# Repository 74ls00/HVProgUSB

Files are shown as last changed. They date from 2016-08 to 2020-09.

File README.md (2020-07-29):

# HVProgUSB

Параллельный программатор AVR на базе STK500. Вход на PL2303, для прошивки программатор не требуется

Инструкция по настройке https://74ls00.github.io/hwprog/help.html

2018.10 добавлен светодиод 3.3в PL2303

Фото моего прибора в папке /pic

Вариант в dip корпусе планировался как тестовый, но заброшен

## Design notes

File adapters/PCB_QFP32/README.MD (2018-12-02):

#### Адаптер для пайки QFP32

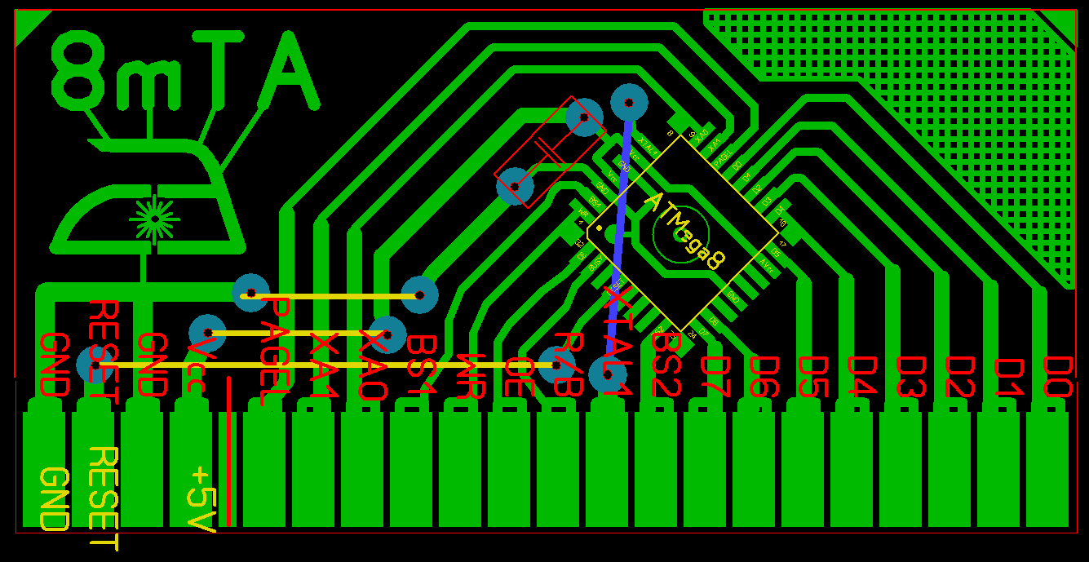
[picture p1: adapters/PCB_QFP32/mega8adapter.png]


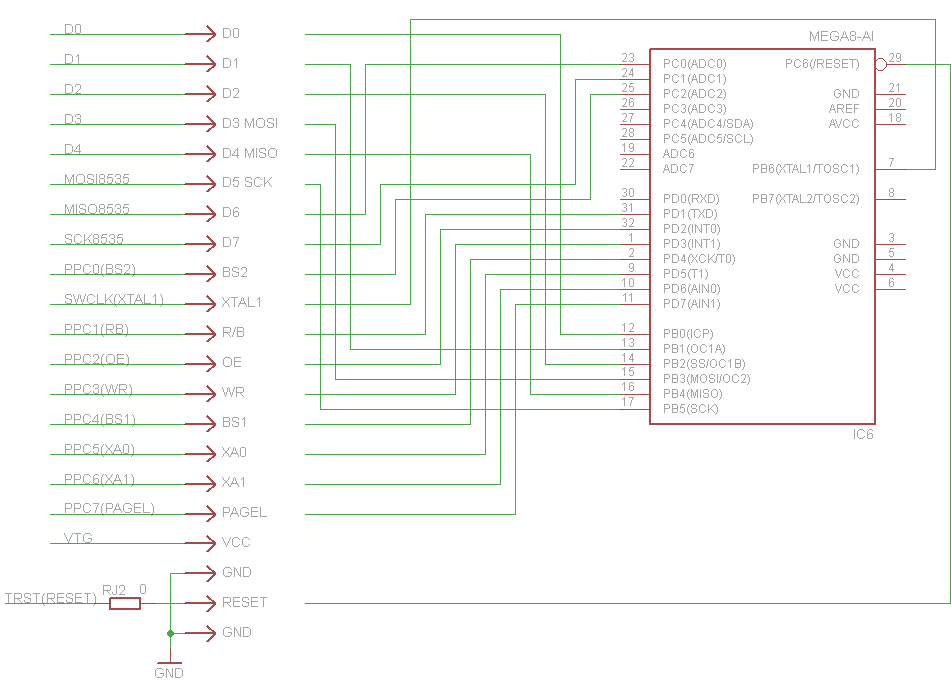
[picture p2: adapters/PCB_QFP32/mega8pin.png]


Плата в формате Sprint-Layout 5

### TODO

добавить крайние на стороне контакты для лучшей центровки.

добавить удлинения за пределы выводлв у нужных выводов

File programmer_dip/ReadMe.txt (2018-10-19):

Эксперементальная плата.
Цель: сборка под DIP компоненты.

Работа не завершена.
Компоненты утеряны, завершение не планируется.

Схема скорее всего завершена.
Плата частично завершена.

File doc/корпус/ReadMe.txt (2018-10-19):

Вариант корпуса.

Размеры возможно не точные, требуют проверки.

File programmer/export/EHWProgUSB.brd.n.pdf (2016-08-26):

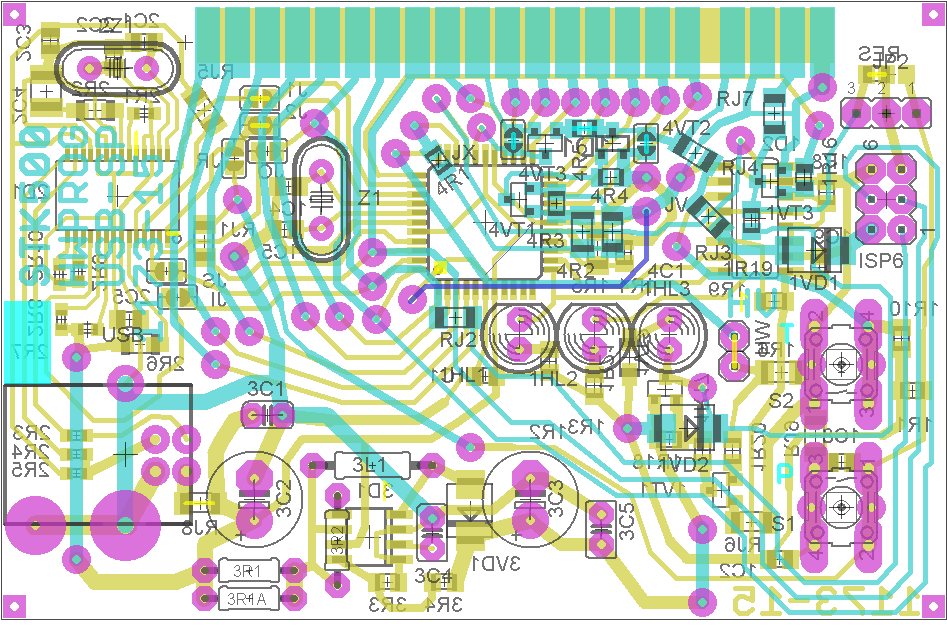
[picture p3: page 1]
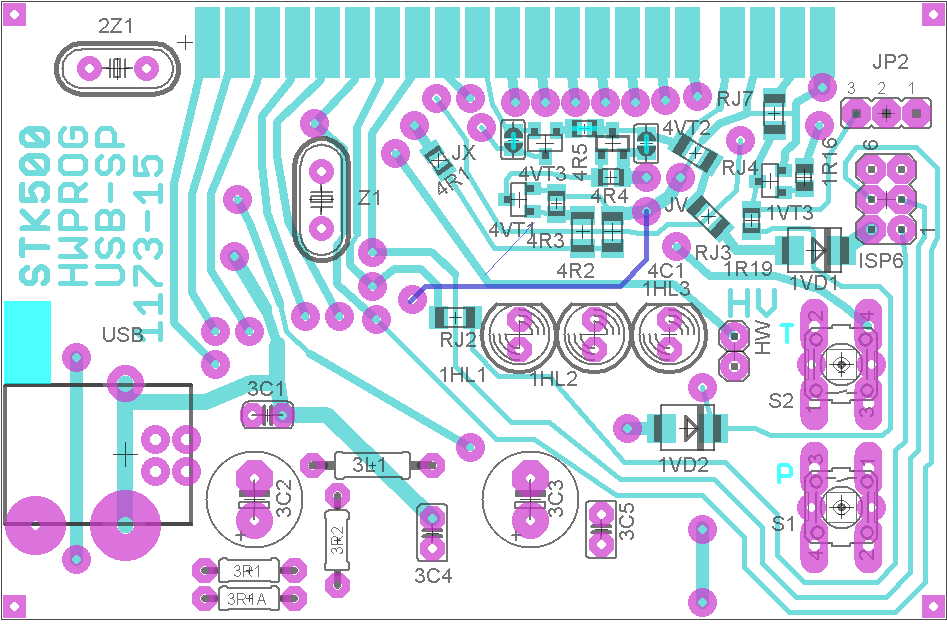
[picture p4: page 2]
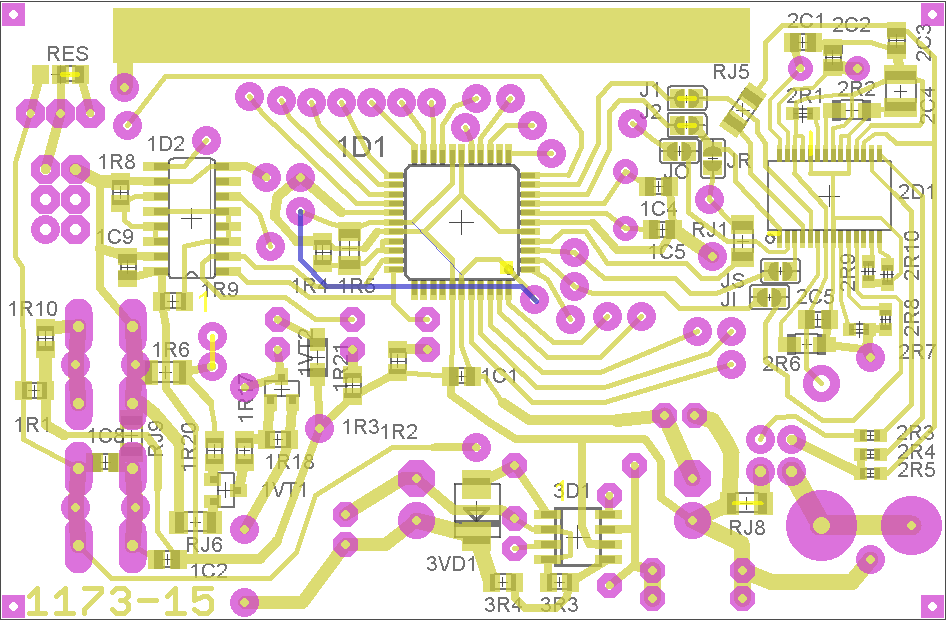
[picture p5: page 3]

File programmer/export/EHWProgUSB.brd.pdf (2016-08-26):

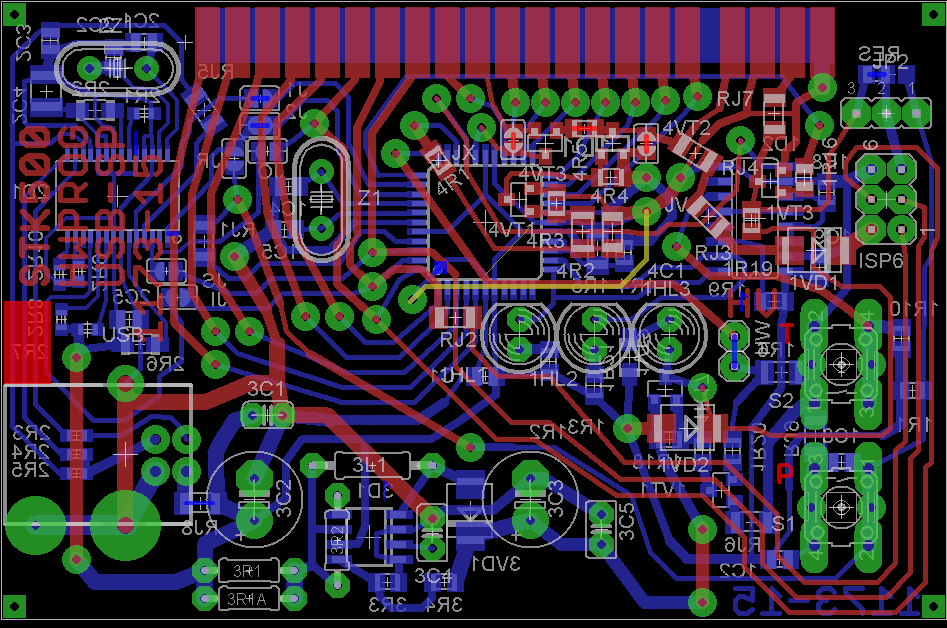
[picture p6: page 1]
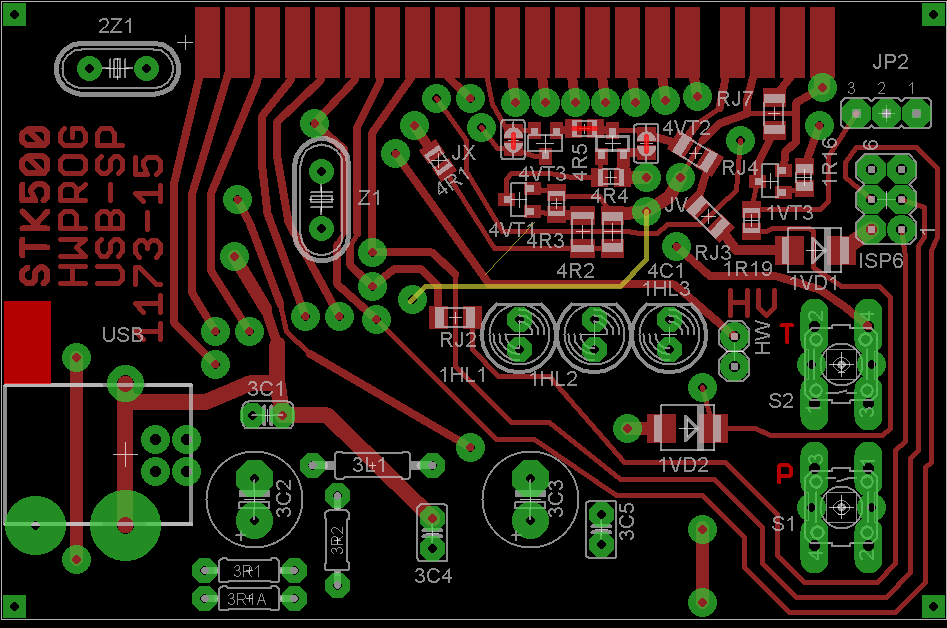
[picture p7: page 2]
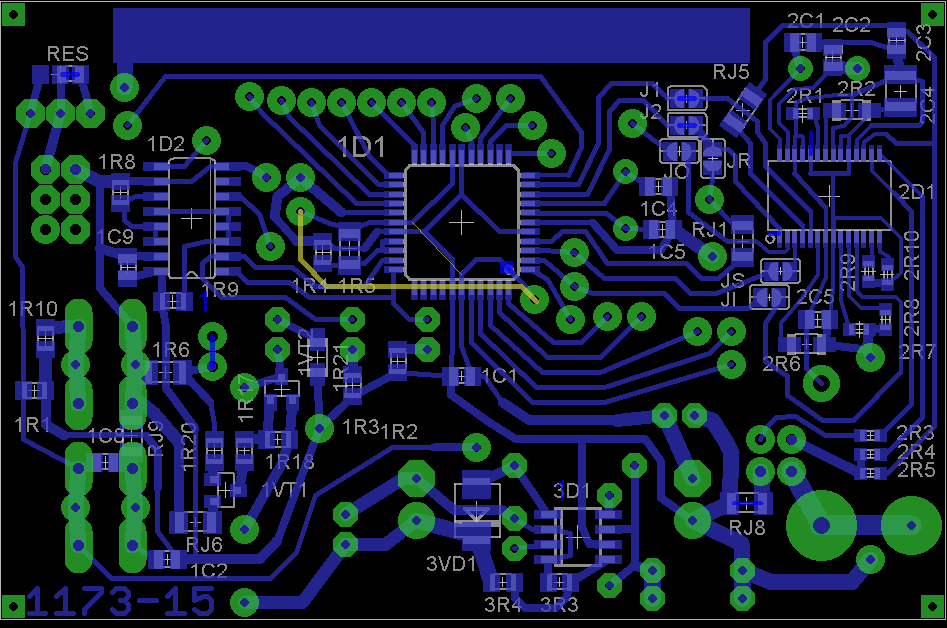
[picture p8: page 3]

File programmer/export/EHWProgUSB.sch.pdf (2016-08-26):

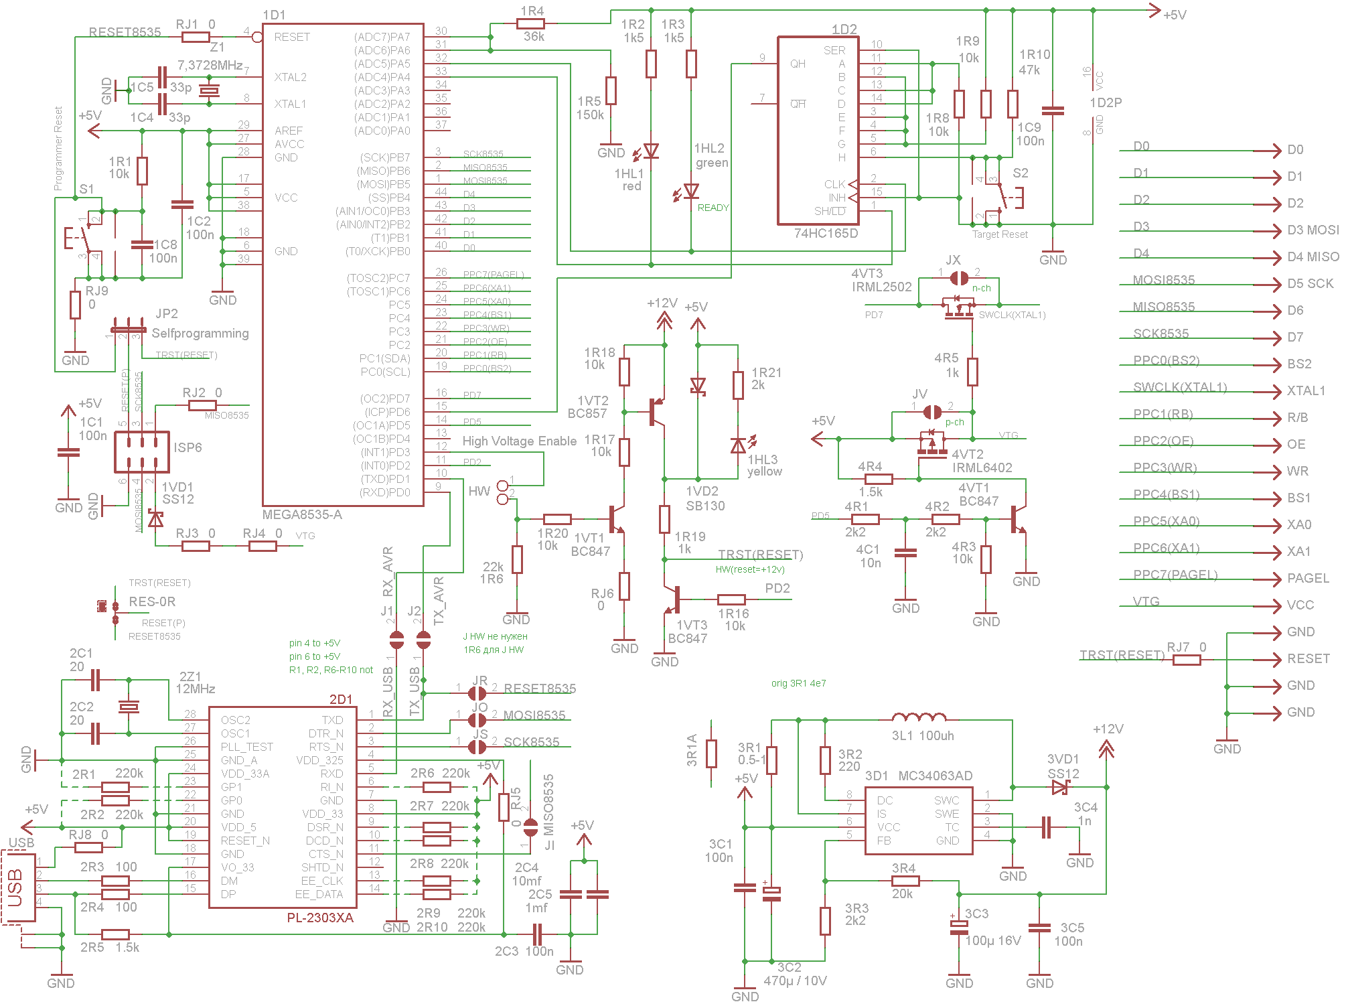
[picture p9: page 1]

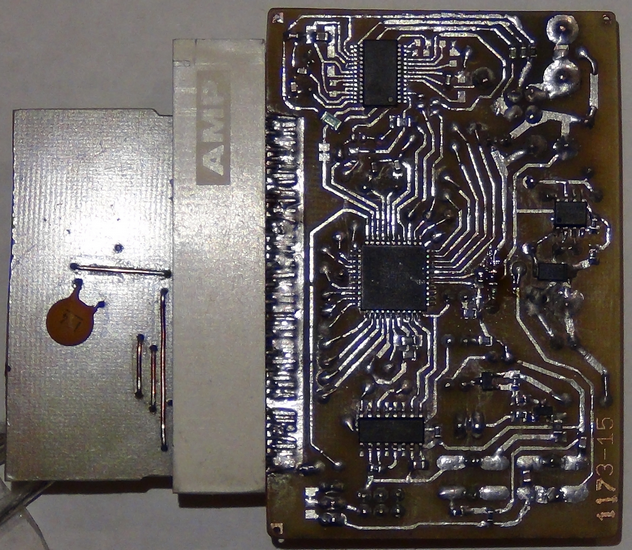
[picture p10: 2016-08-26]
pic/HWProgUSBp2.png

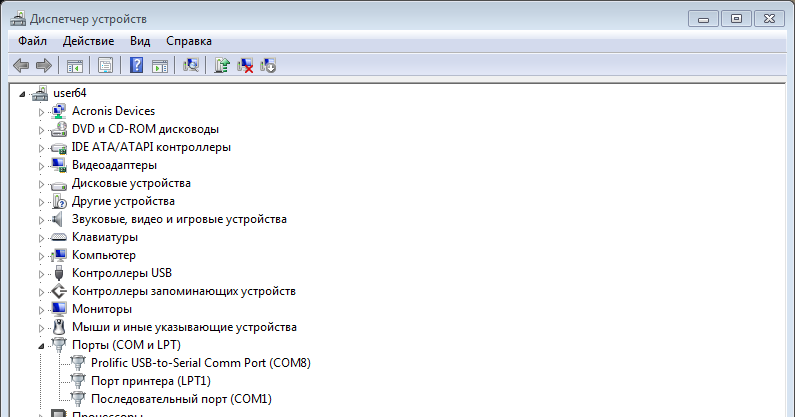
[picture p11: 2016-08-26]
doc/images/devmgr-prolific.png

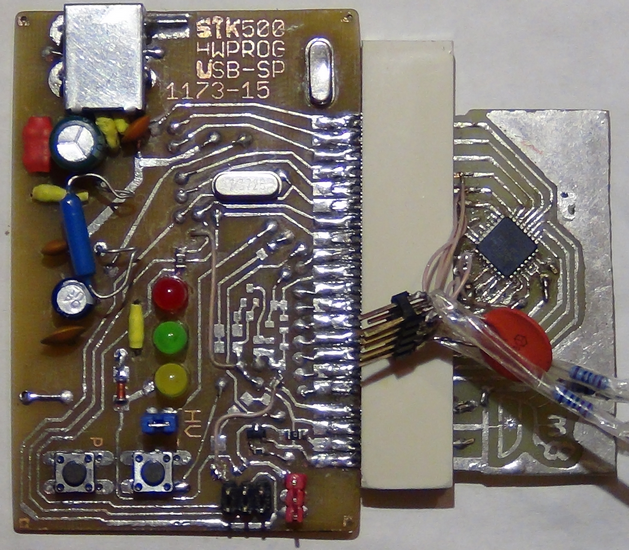
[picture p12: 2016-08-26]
pic/HWProgUSBp1.png

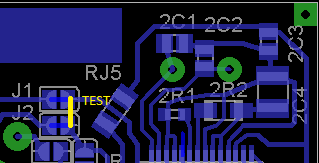
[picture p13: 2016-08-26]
doc/images/j1j2-jumper.png

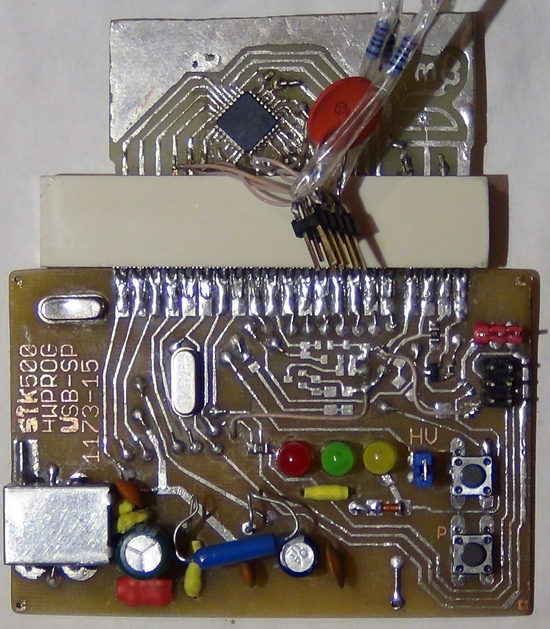
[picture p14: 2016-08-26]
pic/HWProgUSBp1 - копия.png

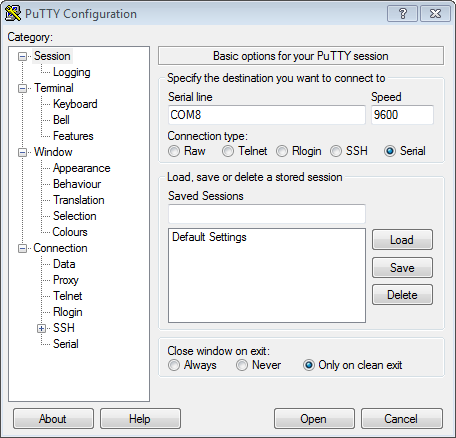
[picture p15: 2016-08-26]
doc/images/putty1.png

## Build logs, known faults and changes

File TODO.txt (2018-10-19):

-=85*69*21 размер в корпусе.

добавить светодиоды rx tx
-выходы isp через резисторы. не обязательно.
dip 3$ разместить микры под ним. polida2008 qfp 2.5$

теоретически mega16 +ch340

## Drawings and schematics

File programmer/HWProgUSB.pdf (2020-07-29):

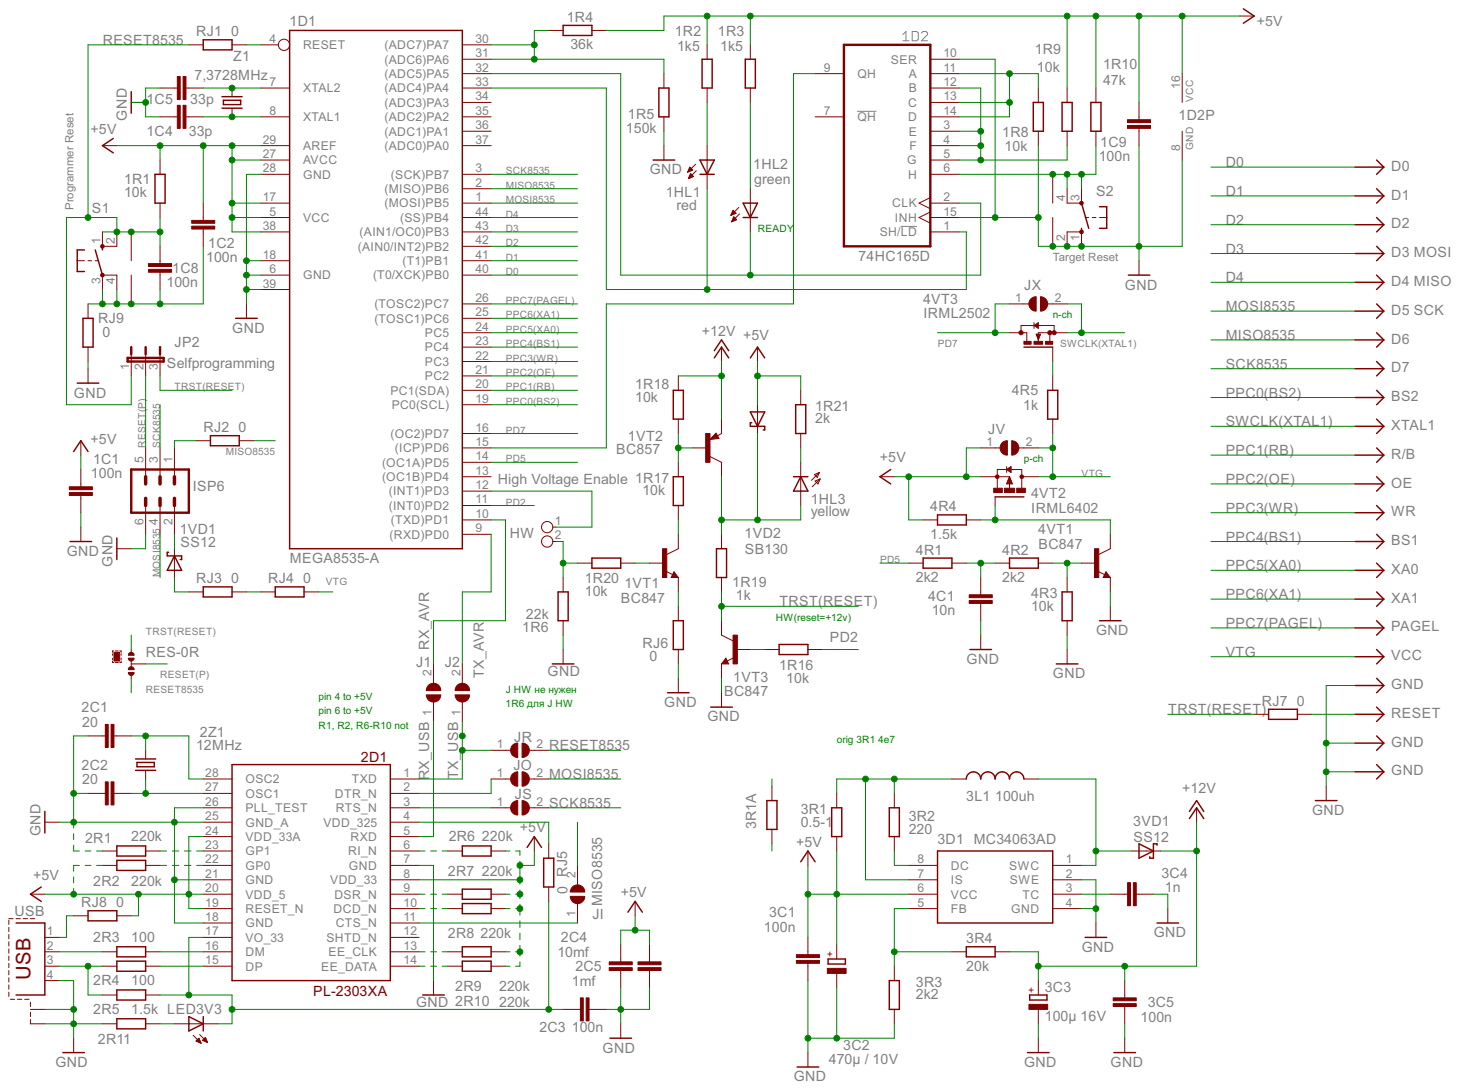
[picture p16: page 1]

Target Reset Programmer Reset 1

6 | 40
39 | 26 PPC7(PAGEL)

pin 4 to +5V R1, R2, R6-R10 not pin 6 to +5V

J HW не нужен 1R6 для J HW

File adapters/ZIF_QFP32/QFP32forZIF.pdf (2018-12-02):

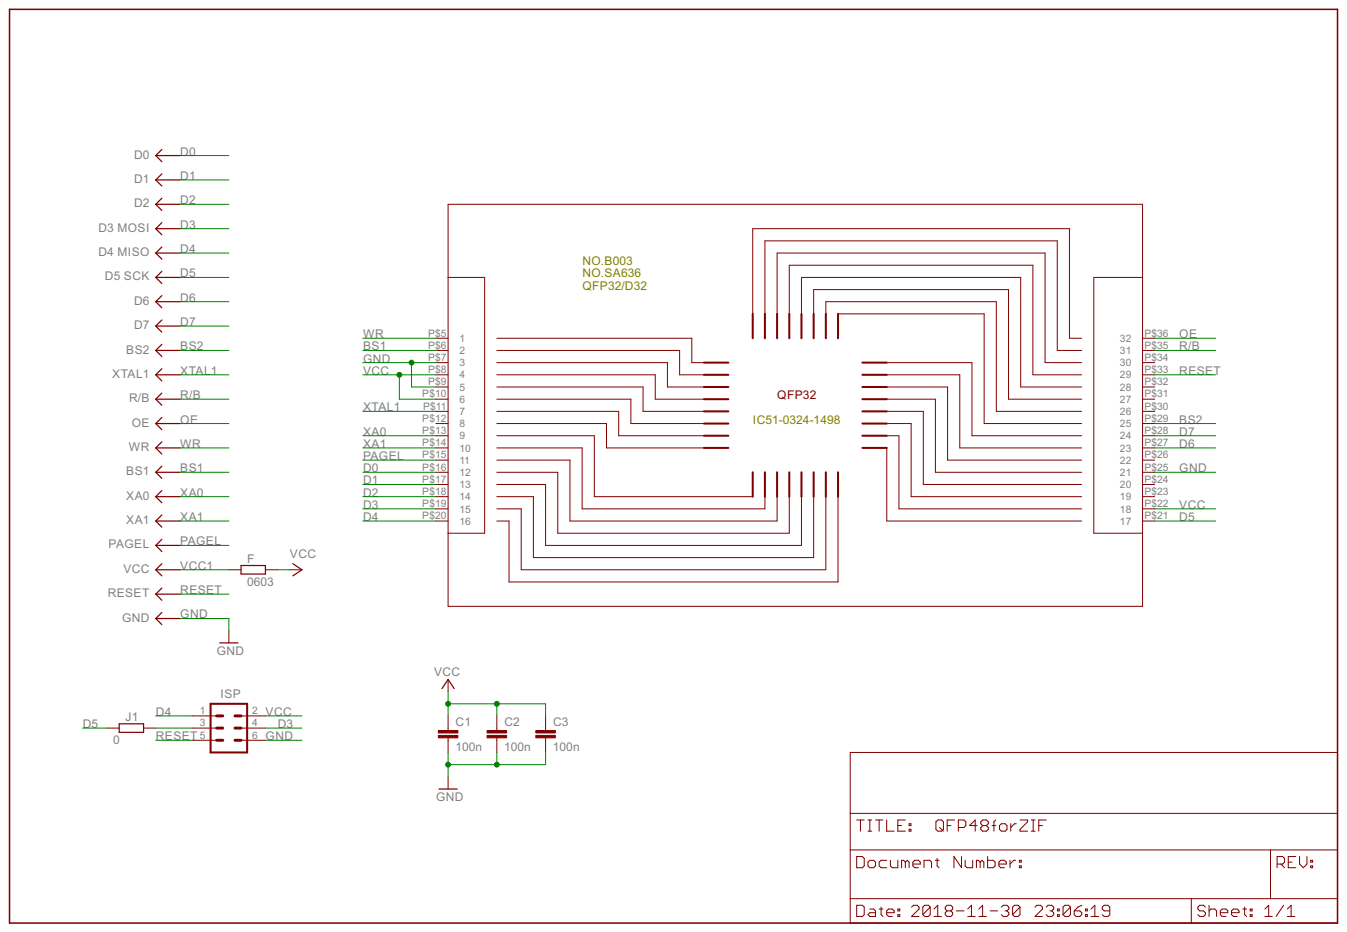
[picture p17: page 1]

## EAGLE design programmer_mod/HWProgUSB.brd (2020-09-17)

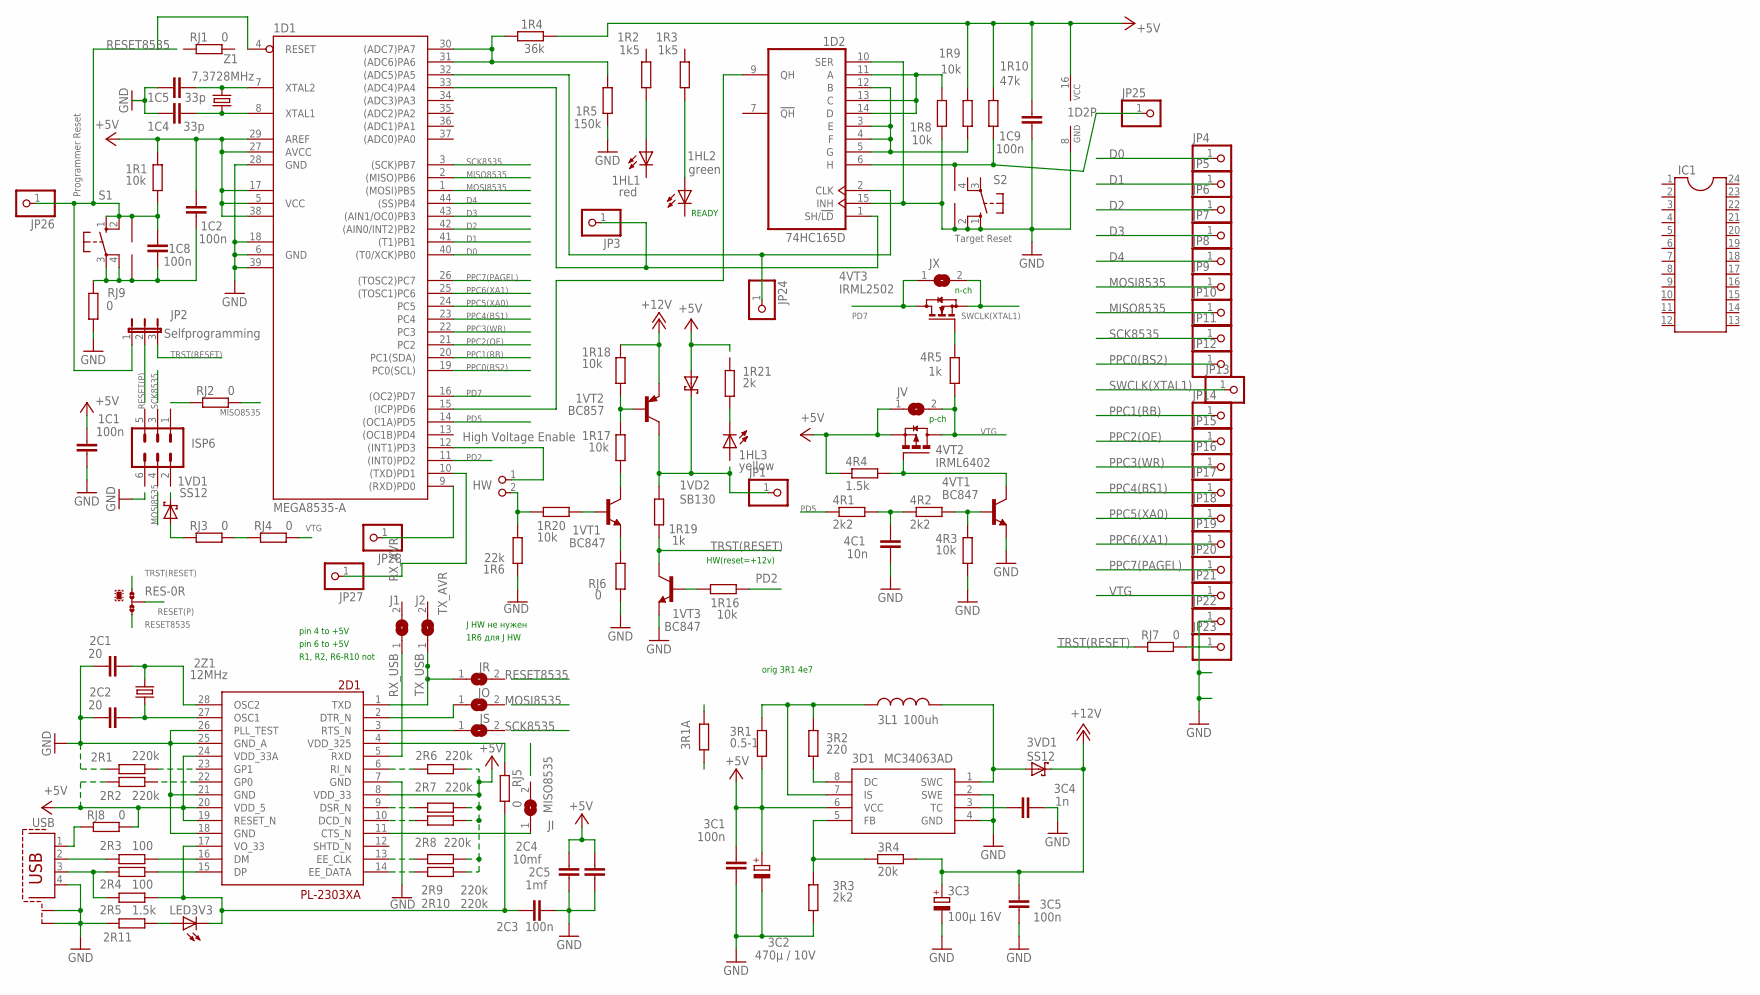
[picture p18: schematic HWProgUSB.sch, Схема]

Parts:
1C1, 1C2, 1C8, 1C9, 2C3: 100n; C0805
1C4, 1C5: 33p; C0805
1D1: MEGA8535-A; TQFP44
1D2: 74HC165D; SO16
1HL1: red; LED5MM
1HL2: green; LED5MM
1HL3: yellow; LED5MM
1R1, 1R8, 1R9, 1R17, 1R18, 1R20, 4R3: 10k; M0805
1R2, 1R3: 1k5; M0805
1R4: 36k; M0805
1R5: 150k; R1206
1R6: 22k; M1206
1R10: 47k; M0805
1R16: 10k; R0805
1R19, 4R5: 1k; M0805
1R21: 2k; R1206W
1VD1, 3VD1: SS12; SMB
1VD2: SB130; SMB
1VT1, 1VT3, 4VT1: BC847; SOT23
1VT2: BC857; SOT23-BEC
2C1, 2C2: 20; C0805
2C4: 10mf; C1210
2C5: 1mf; C0805
2D1: PL-2303XA; SSOP28DB
2R1, 2R7, 2R8, 2R9, 2R10: 220k; R0603
2R2, 2R6: 220k; R1206W
2R3, 2R4: 100; R0603
2R5: 1.5k; R0603
2R11: R-EU_R0603; R0603
2Z1: 12MHz; HC49/S
3C1: 100n; C025-024X044
3C2: 470µ / 10V; RCL_E3,5-8
3C3: 100µ 16V; RCL_E3,5-8
3C4: 1n; C025-025X050
3C5: 100n; C025-025X050
3D1: MC34063AD; SOIC8
3L1: 100uh; 0207/10
3R1: 0.5-1; 0204/7
3R1A: R-EU_0204/7; 0204/7
3R2: 220; 0204/7
3R3, 4R1: 2k2; M0805
3R4: 20k; M0805
4C1: 10n; C1206
4R2: 2k2; M1206
4R4: 1.5k; M0805
4VT2: IRML6402; SUPER-SOT3
4VT3: IRML2502; SOT23
HW: High Voltage Enable; PINHEAD_1X02
IC1: DIL24-9
ISP6: MA03-2
J1, J2: SJ
JI: SJ
JO: SJ
JP1, JP3, JP4, JP5, JP6, JP7, JP8, JP9, JP10, JP11, JP12, JP13, JP14, JP15, JP16, JP17, JP18, JP19, JP20, JP21, JP22, JP23, JP24, JP25, JP26, JP27, JP28: PINHD-1X1; 1X01
JP2: Selfprogramming; JUMPER_JP2
JR: SJ
JS: SJ
JV: SJ
JX: SJ
LED3V3: LEDCHIPLED_0603; CHIPLED_0603
RES: 0R-JUMPA; A0R-JMP
RJ1, RJ2, RJ3, RJ4, RJ5, RJ6, RJ7, RJ8, RJ9: 0; R1206
S1, S2: 10-XX; B3F-10XX
U$1, U$2: 5.08; KEY
USB: PROGRAMMER_PN61729-S
Z1: 7,3728MHz; HC49U-V

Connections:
3VUSB: 2C3.1, 2D1.17 (VO_33), 2R5.1, LED3V3.C, RJ5.2
+5V: 1C1.2, 1C2.2, 1C9.1, 1D1.5 (VCC), 1D1.17 (VCC1), 1D1.27 (AVCC), 1D1.29 (AREF), 1D1.38 (VCC2), 1D2.16 (VCC), 1R1.2, 1R4.2, 1R9.1, 1R10.1, 1VD2.A, 2C4.2, 2C5.2, 2D1.8 (VDD_33), 2D1.19 (RESET_N), 2D1.20 (VDD_5), 2D1.24 (VDD_33A), 2R2.1, 2R6.2, 2R7.1, 2R8.1, 2R9.1, 2R10.1, 3C1.1, 3C2.+, 3D1.6 (VCC), 3R1.1, 3R1A.1, 4R4.1, 4VT2.2 (S), JV.1, RJ8.2
+12V: 1R18.2, 1VT2.E, 3C3.+, 3C5.2, 3R4.2, 3VD1.C
D0: 1D1.40 ((T0/XCK)PB0), JP4.1
D1: 1D1.41 ((T1)PB1), JP5.1
D2: 1D1.42 ((AIN0/INT2)PB2), JP6.1
D3: 1D1.43 ((AIN1/OC0)PB3), JP7.1
D4: 1D1.44 ((SS)PB4), JP8.1
GND: 1C1.1, 1C4.1, 1C5.1, 1C9.2, 1D1.6 (GND), 1D1.18 (GND1), 1D1.28 (GND), 1D1.39 (GND2), 1D2.8 (GND), 1D2.10 (SER), 1D2.15 (INH), 1R5.1, 1R6.1, 1R8.1, 1VT3.2 (E), 2C1.1, 2C2.1, 2C3.2, 2C4.1, 2C5.1, 2D1.7 (GND), 2D1.18 (GND), 2D1.21 (GND), 2D1.25 (GND_A), 2D1.26 (PLL_TEST), 2R1.1, 2R11.2, 3C1.2, 3C2.-, 3C3.-, 3C4.2, 3C5.1, 3D1.2 (SWE), 3D1.4 (GND), 3R3.1, 4C1.1, 4R3.1, 4VT1.2 (E), JP22.1, RJ6.1, RJ9.1, S2.1 (S), S2.2 (S1), U$2.P$1, USB.4, USB.S1, USB.S2
MISO8535: 1D1.2 ((MISO)PB6), JP10.1, RJ2.2
MOSI8535: 1D1.1 ((MOSI)PB5), JP9.1
N4: 1D1.33 ((ADC4)PA4), 1D2.1 (SH/!LD), JP3.1
unnamed: JP23.1, RJ7.2
unnamed: 2D1.4 (VDD_325), RJ5.1
unnamed: 1VT1.2 (E), RJ6.2
unnamed: 2D1.9 (DSR_N), 2R7.2
unnamed: 1VD1.A, RJ3.1
unnamed: RJ3.2, RJ4.1
unnamed: 1C5.2, 1D1.7 (XTAL2), Z1.2
unnamed: 1C4.2, 1D1.8 (XTAL1), Z1.1
unnamed: RJ8.1, USB.1
unnamed: 1C2.1, 1C8.1, RJ9.2, S1.3, S1.4 (P1), U$1.P$1
unnamed: 1HL3.K (C), 1R21.1
unnamed: 4R5.2, 4VT3.1 (G)
unnamed: 2R11.1, LED3V3.A
unnamed: 2R4.1, 2R5.2, USB.3
unnamed: 2R3.1, USB.2
unnamed: 2D1.15 (DP), 2R4.2
unnamed: 2D1.16 (DM), 2R3.2
unnamed: 2D1.23 (GP1), 2R1.2
unnamed: 2D1.22 (GP0), 2R2.2
unnamed: 2C1.2, 2D1.28 (OSC2), 2Z1.2
unnamed: 2D1.11 (CTS_N), JI.1
unnamed: 4R2.2, 4R3.2, 4VT1.1 (B)
unnamed: 2C2.2, 2D1.27 (OSC1), 2Z1.1
unnamed: 2D1.6 (RI_N), 2R6.1
unnamed: 4R4.2, 4VT1.3 (C), 4VT2.1 (G)
unnamed: 2D1.3 (RTS_N), JS.1
unnamed: 4C1.2, 4R1.2, 4R2.1
unnamed: 2D1.13 (EE_CLK), 2R9.2
unnamed: 2D1.2 (DTR_N), JO.1
unnamed: 2D1.14 (EE_DATA), 2R10.2
unnamed: 2D1.10 (DCD_N), 2R8.2
unnamed: 3D1.8 (DC), 3R2.1
unnamed: 3D1.7 (IS), 3L1.1, 3R1.2, 3R1A.2, 3R2.2
unnamed: 3D1.5 (FB), 3R3.2, 3R4.1
unnamed: 3D1.1 (SWC), 3L1.2, 3VD1.A
unnamed: 3C4.1, 3D1.3 (TC)
unnamed: 1HL2.A, 1R3.1
unnamed: 1D1.30 ((ADC7)PA7), 1D1.31 ((ADC6)PA6), 1R4.1, 1R5.2
unnamed: 1D1.32 ((ADC5)PA5), 1D2.2 (CLK), JP24.1
unnamed: 1D2.6 (H), 1R10.2, JP25.1, U$2.P$2
unnamed: 1D1.12 ((INT1)PD3), HW.1
unnamed: 1R6.2, 1R20.2, HW.2
unnamed: 1R19.2, 1VD2.C, 1VT2.C, JP1.1
unnamed: 1R20.1, 1VT1.1 (B)
unnamed: 1R17.1, 1VT1.3 (C)
unnamed: 1R17.2, 1R18.1, 1VT2.B
unnamed: 1D1.15 ((ICP)PD6), 1D2.9 (QH)
unnamed: 1HL1.A, 1R2.1
unnamed: 1D2.11 (A), 1D2.13 (C), 1D2.14 (D), 1R8.2
unnamed: 1D2.3 (E), 1D2.4 (F), 1D2.5 (G), 1D2.12 (B), 1R9.2
unnamed: 1R16.2, 1VT3.1 (B)
PD2: 1D1.11 ((INT0)PD2), 1R16.1
PD5: 1D1.14 ((OC1A)PD5), 4R1.1
PD7: 1D1.16 ((OC2)PD7), 4VT3.3 (D), JX.1
PPC0(BS2): 1D1.19 (PC0(SCL)), JP12.1
PPC1(RB): 1D1.20 (PC1(SDA)), JP14.1
PPC2(OE): 1D1.21 (PC2), JP15.1
PPC3(WR): 1D1.22 (PC3), JP16.1
PPC4(BS1): 1D1.23 (PC4), JP17.1
PPC5(XA0): 1D1.24 (PC5), JP18.1
PPC6(XA1): 1D1.25 ((TOSC1)PC6), JP19.1
PPC7(PAGEL): 1D1.26 ((TOSC2)PC7), JP20.1
RESET8535: 1C8.2, 1D1.4 (RESET), 1R1.1, JP2.1, JP26.1, RES.3, S1.1 (S), S1.2 (S1), U$1.P$2
RESET(P): JP2.2, RES.2
RX_AVR: 1D1.10 ((TXD)PD1), JP27.1
RX_USB: 2D1.5 (RXD), J1.1
SCK8535: 1D1.3 ((SCK)PB7), JP11.1
SWCLK(XTAL1): 4VT3.2 (S), JP13.1, JX.2
TRST(RESET): 1R19.1, 1VT3.3 (C), JP2.3, RES.1, RJ7.1
TX_AVR: 1D1.9 ((RXD)PD0), JP28.1
TX_USB: 2D1.1 (TXD), J2.1, JR.1
VTG: 4R5.1, 4VT2.3 (D), JP21.1, JV.2, RJ4.2

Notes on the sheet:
Target Reset
Programmer Reset
pin 4 to +5V
R1, R2, R6-R10 not
pin 6 to +5V
orig 3R1 4e7
J HW не нужен
1R6 для J HW
HW(reset=+12v)
READY
n-ch
p-ch

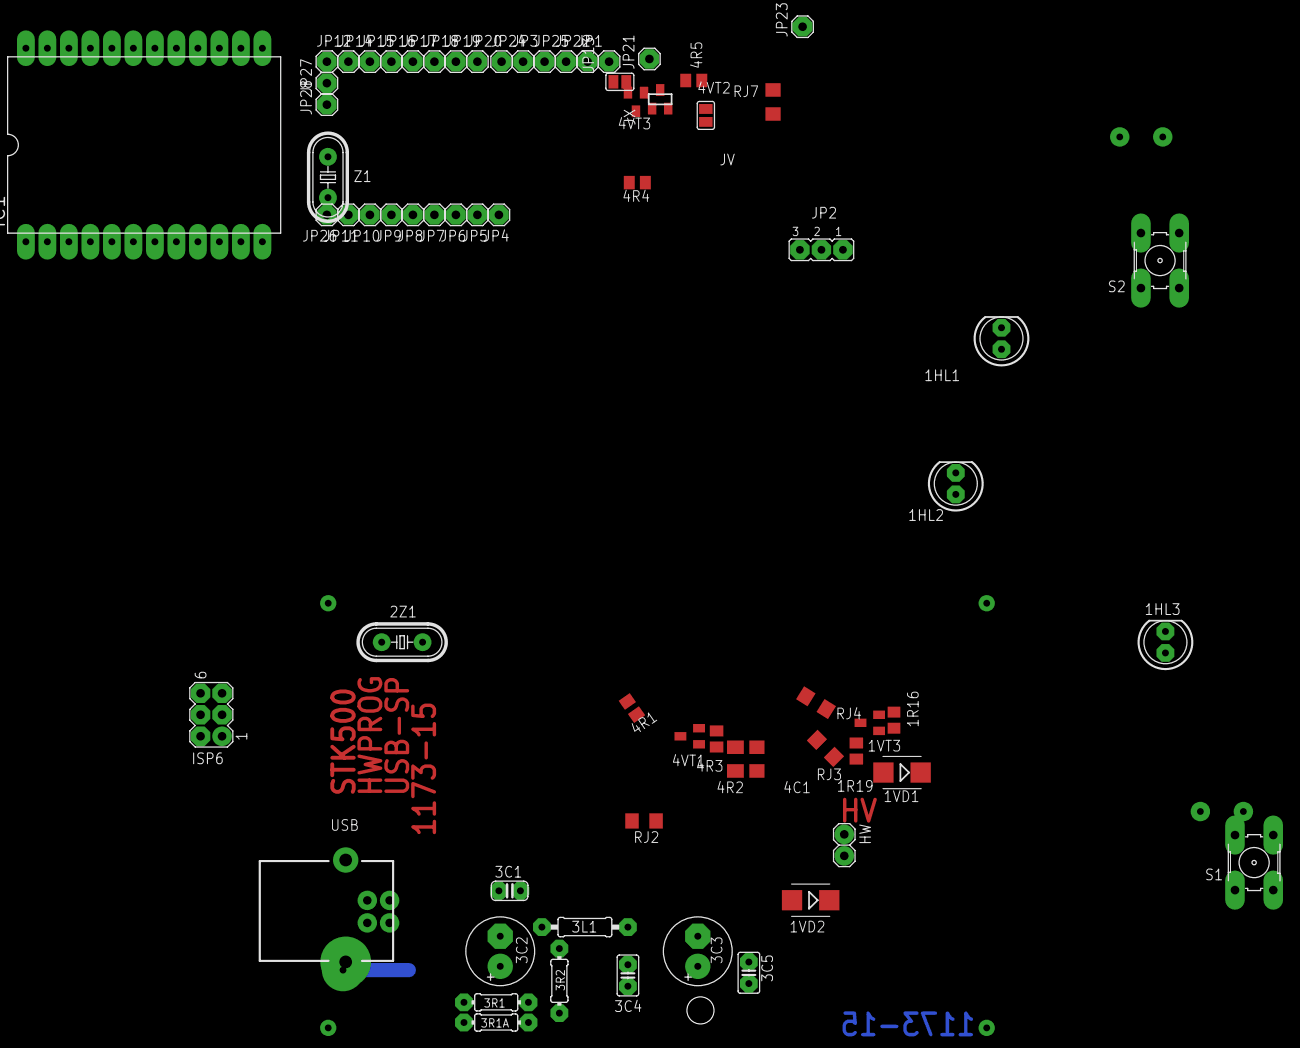
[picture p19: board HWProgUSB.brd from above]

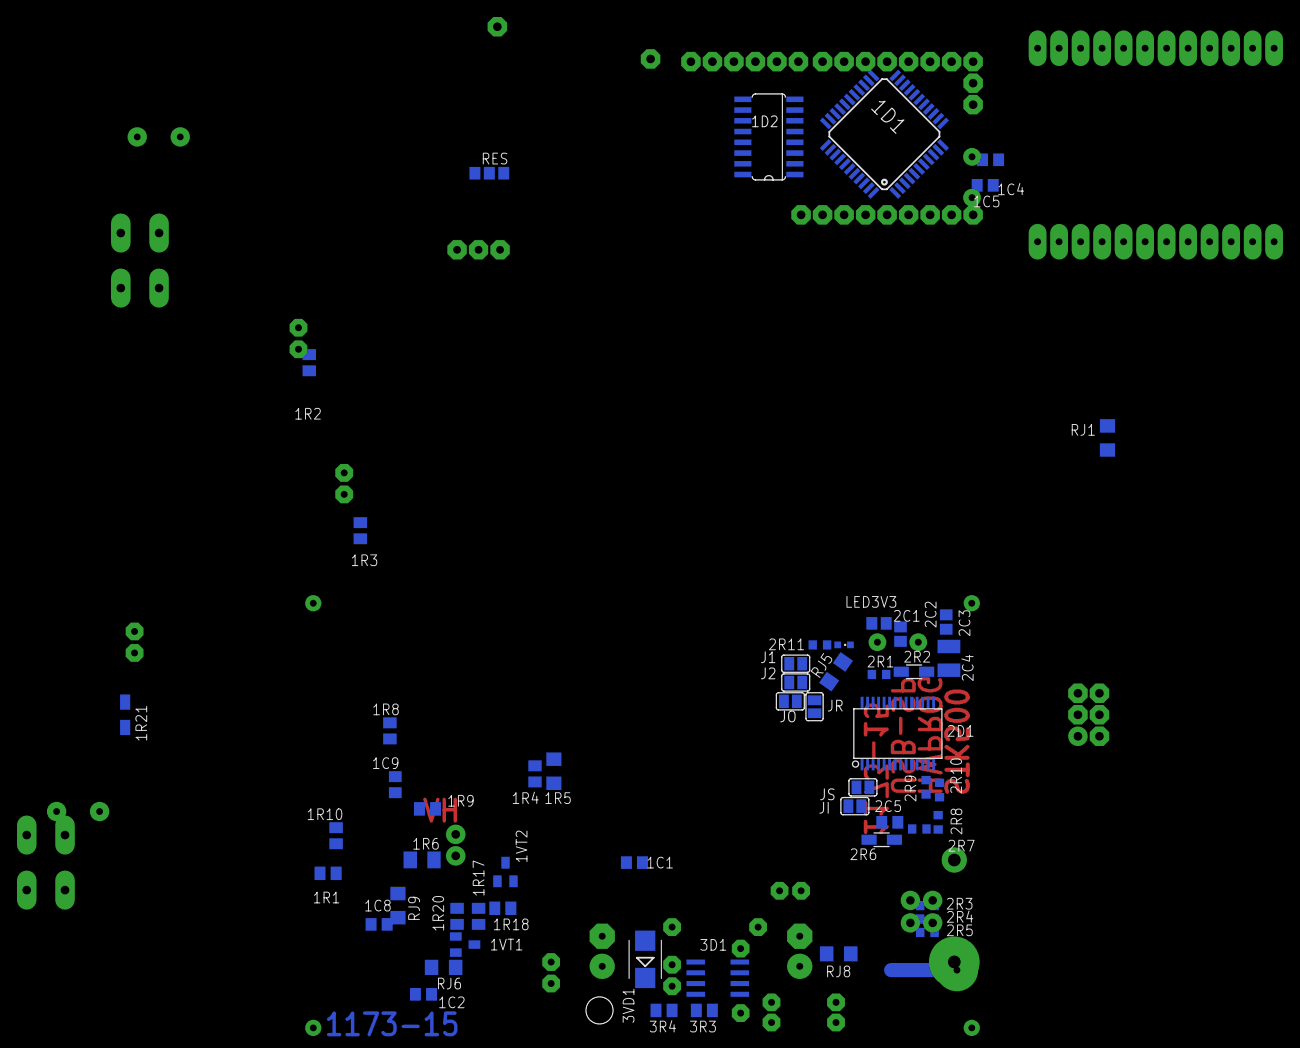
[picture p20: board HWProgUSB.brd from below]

Board: 2 copper layers, 127 parts (57 on the bottom side), 84 nets.

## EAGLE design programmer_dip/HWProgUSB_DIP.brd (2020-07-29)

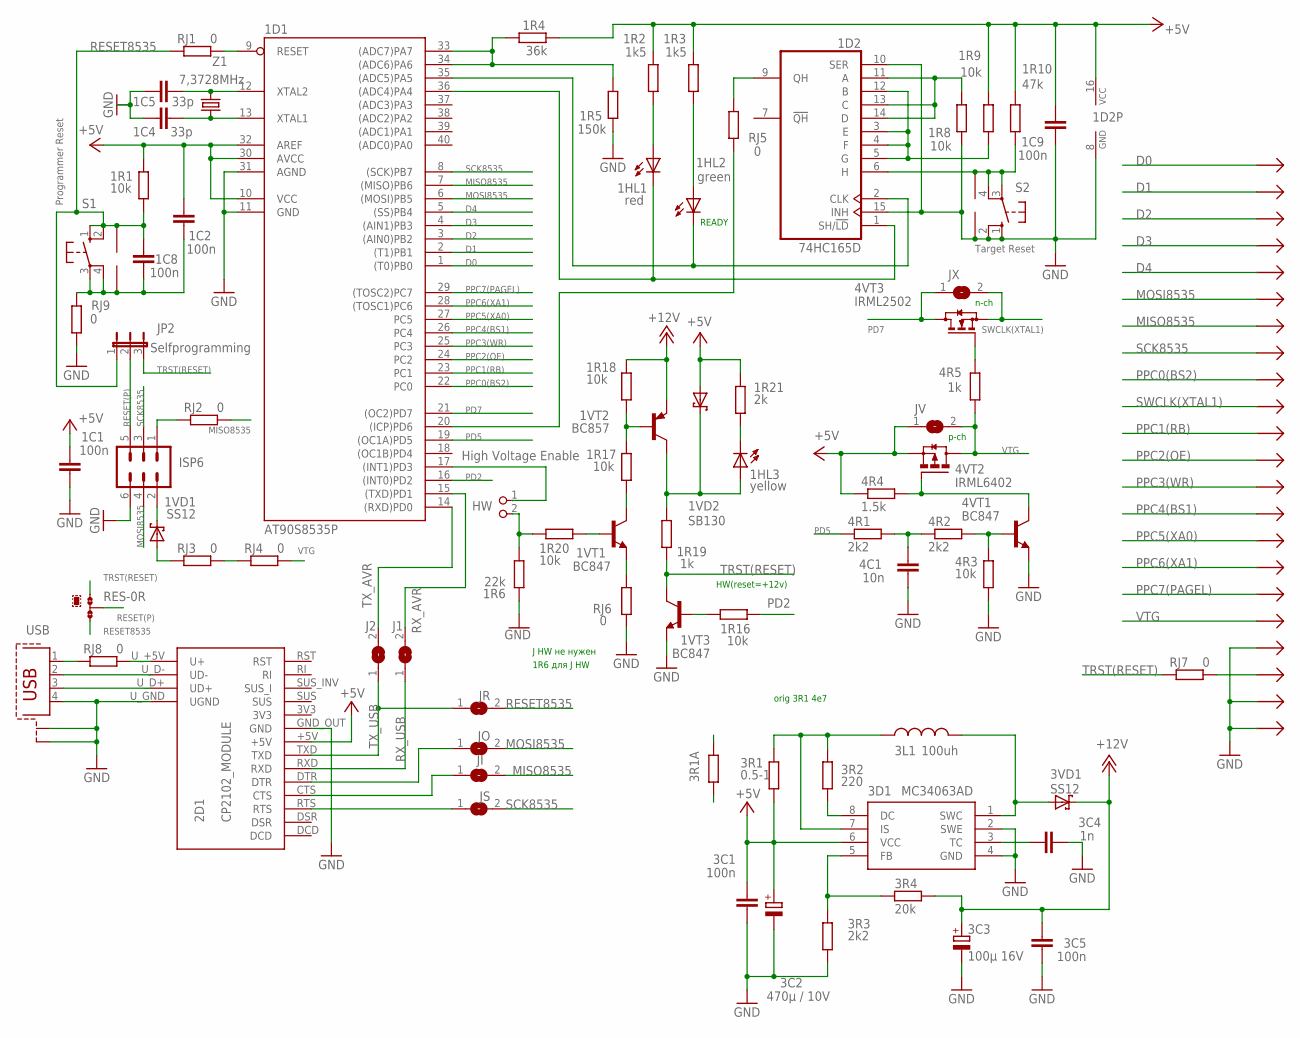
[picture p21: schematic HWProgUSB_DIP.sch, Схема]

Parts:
1C1, 1C2, 1C8, 1C9: 100n; C0805
1C4, 1C5: 33p; C0805
1D1: AT90S8535P; DIL40
1D2: 74HC165D; SO16
1HL1: red; LED5MM
1HL2: green; LED5MM
1HL3: yellow; LED5MM
1R1, 1R8, 1R17, 1R18, 1R20, 4R3: 10k; M0805
1R2, 1R3: 1k5; M0805
1R4: 36k; M0805
1R5: 150k; R1206W
1R6: 22k; M1206
1R9: 10k; R1206W
1R10: 47k; M0805
1R16: 10k; R0805
1R19, 4R5: 1k; M0805
1R21: 2k; R1206W
1VD1, 3VD1: SS12; SMB
1VD2: SB130; SMB
1VT1, 1VT3, 4VT1: BC847; SOT23
1VT2: BC857; SOT23-BEC
2D1: CP2102_MODULE
3C1: 100n; C025-024X044
3C2: 470µ / 10V; RCL_E3,5-8
3C3: 100µ 16V; RCL_E3,5-8
3C4: 1n; C025-025X050
3C5: 100n; C025-025X050
3D1: MC34063AD; SOIC8
3L1: 100uh; 0207/10
3R1: 0.5-1; 0204/7
3R1A: R-EU_0204/7; 0204/7
3R2: 220; 0204/7
3R3, 4R2: 2k2; M0805
3R4: 20k; M0805
4C1: 10n; C1206
4R1: 2k2; R1206W
4R4: 1.5k; M0805
4VT2: IRML6402; SUPER-SOT3
4VT3: IRML2502; SOT23
HW: High Voltage Enable; PINHEAD_1X02
ISP6: MA03-2
J1, J2: SJ
JI: SJ
JO: SJ
JP2: Selfprogramming; JUMPER_JP2
JR: SJ
JS: SJ
JV: SJ
JX: SJ
RES: 0R-JUMPA; A0R-JMP
RJ1, RJ2, RJ3, RJ4, RJ6, RJ7, RJ8, RJ9: 0; R1206
RJ5: 0; R1206W
S1, S2: 10-XX; B3F-10XX
U$1, U$2: 5.08; KEY
USB: PROGRAMMER_PN61729-S
X2: P_AVR_V; CON-PCI
Z1: 7,3728MHz; HC49U-V

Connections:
+5V: 1C1.2, 1C2.2, 1C9.1, 1D1.10 (VCC), 1D1.30 (AVCC), 1D1.32 (AREF), 1D2.16 (VCC), 1R1.2, 1R2.2, 1R3.2, 1R4.2, 1R9.1, 1R10.1, 1R21.2, 1VD2.A, 2D1.+5V, 3C1.1, 3C2.+, 3D1.6 (VCC), 3R1.1, 3R1A.1, 4R4.1, 4VT2.2 (S), JV.1
+12V: 1R18.2, 1VT2.E, 3C3.+, 3C5.2, 3R4.2, 3VD1.C
D0: 1D1.1 ((T0)PB0), X2.1D0 (D0), X2.2D0 (D0)
D1: 1D1.2 ((T1)PB1), X2.1D1 (D1), X2.2D1 (D1)
D2: 1D1.3 ((AIN0)PB2), X2.1D2 (D2), X2.2D2 (D2)
D3: 1D1.4 ((AIN1)PB3), X2.1D3 (D3), X2.2D3 (D3)
D4: 1D1.5 ((SS)PB4), X2.1D4 (D4), X2.2D4 (D4)
GND: 1C1.1, 1C4.1, 1C5.1, 1C9.2, 1D1.11 (GND), 1D1.31 (AGND), 1D2.8 (GND), 1D2.10 (SER), 1D2.15 (INH), 1R5.1, 1R6.1, 1R8.1, 1VT3.2 (E), 2D1.GND_OUT (GND), 2D1.U_GND (UGND), 3C1.2, 3C2.-, 3C3.-, 3C4.2, 3C5.1, 3D1.2 (SWE), 3D1.4 (GND), 3R3.1, 4C1.1, 4R3.1, 4VT1.2 (E), ISP6.6, RJ6.1, RJ9.1, S2.1 (S), S2.2 (S1), U$2.P$1, USB.4, USB.S1, USB.S2, X2.0 (GND), X2.1 (GND), X2.1GND1 (GND2), X2.1GND2 (LGND), X2.2 (GND), X2.2GND1 (GND2), X2.2GND2 (LGND), X2.3 (GND), X2.4 (GND), X2.5 (GND), X2.6 (GND), X2.7 (GND), X2.8 (GND), X2.9 (GND), X2.10 (GND), X2.11 (GND), X2.12 (GND), X2.13 (GND), X2.14 (GND), X2.15 (GND), X2.16 (GND), X2.17 (GND), X2.18 (GND), X2.19 (GND), X2.20 (GND), X2.21 (GND), X2.22 (GND), X2.23 (GND), X2.24 (GND), X2.25 (GND), X2.26 (GND), X2.27 (GND), X2.28 (GND), X2.29 (GND), X2.30 (GND), X2.31 (GND), X2.32 (GND), X2.33 (GND), X2.34 (GND), X2.35 (GND), X2.36 (GND), X2.37 (GND), X2.38 (GND), X2.39 (GND), X2.40 (GND), X2.41 (GND)
MISO8535: 1D1.7 ((MISO)PB6), JI.2, RJ2.2, X2.1D6 (D6), X2.2D6 (D6)
MOSI8535: 1D1.6 ((MOSI)PB5), ISP6.4, JO.2, X2.1D5 (D5), X2.2D5 (D5)
N4: 1D1.36 ((ADC4)PA4), 1D2.1 (SH/!LD), 1HL1.K (C)
unnamed: RJ7.2, X2.1RESET (RESET), X2.2RESET (RESET)
unnamed: 1D1.9 (RESET), RJ1.2
unnamed: ISP6.1, RJ2.1
unnamed: 2D1.U_+5V (U+), RJ8.2
unnamed: 1VT1.2 (E), RJ6.2
unnamed: 1VD1.C, ISP6.2
unnamed: 2D1.CTS, JI.1
unnamed: 1VD1.A, RJ3.1
unnamed: RJ3.2, RJ4.1
unnamed: 1C5.2, 1D1.12 (XTAL2), Z1.2
unnamed: 1C4.2, 1D1.13 (XTAL1), Z1.1
unnamed: RJ8.1, USB.1
unnamed: 1C2.1, 1C8.1, RJ9.2, S1.3, S1.4 (P1), U$1.P$1
unnamed: 1HL3.K (C), 1R21.1
unnamed: 4R5.2, 4VT3.1 (G)
unnamed: 1D2.9 (QH), RJ5.2
unnamed: 2D1.U_D+ (UD+), USB.3
unnamed: 2D1.U_D- (UD-), USB.2
unnamed: 4R2.2, 4R3.2, 4VT1.1 (B)
unnamed: 4R4.2, 4VT1.3 (C), 4VT2.1 (G)
unnamed: 2D1.RTS, JS.1
unnamed: 4C1.2, 4R1.2, 4R2.1
unnamed: 2D1.DTR, JO.1
unnamed: 3D1.8 (DC), 3R2.1
unnamed: 3D1.7 (IS), 3L1.1, 3R1.2, 3R1A.2, 3R2.2
unnamed: 3D1.5 (FB), 3R3.2, 3R4.1
unnamed: 3D1.1 (SWC), 3L1.2, 3VD1.A
unnamed: 3C4.1, 3D1.3 (TC)
unnamed: 1HL2.A, 1R3.1
unnamed: 1D1.33 ((ADC7)PA7), 1D1.34 ((ADC6)PA6), 1R4.1, 1R5.2
unnamed: 1D1.35 ((ADC5)PA5), 1D2.2 (CLK), 1HL2.K (C)
unnamed: 1D2.6 (H), 1R10.2, S2.3, S2.4 (P1), U$2.P$2
unnamed: 1D1.17 ((INT1)PD3), HW.1
unnamed: 1R6.2, 1R20.2, HW.2
unnamed: 1HL3.A, 1R19.2, 1VD2.C, 1VT2.C
unnamed: 1R20.1, 1VT1.1 (B)
unnamed: 1R17.1, 1VT1.3 (C)
unnamed: 1R17.2, 1R18.1, 1VT2.B
unnamed: 1D1.20 ((ICP)PD6), RJ5.1
unnamed: 1HL1.A, 1R2.1
unnamed: 1D2.11 (A), 1D2.13 (C), 1D2.14 (D), 1R8.2
unnamed: 1D2.3 (E), 1D2.4 (F), 1D2.5 (G), 1D2.12 (B), 1R9.2
unnamed: 1R16.2, 1VT3.1 (B)
PD2: 1D1.16 ((INT0)PD2), 1R16.1
PD5: 1D1.19 ((OC1A)PD5), 4R1.1
PD7: 1D1.21 ((OC2)PD7), 4VT3.3 (D), JX.1
PPC0(BS2): 1D1.22 (PC0), X2.1BS2 (BS2), X2.2BS2 (BS2)
PPC1(RB): 1D1.23 (PC1), X2.1RB (RB), X2.2RB (RB)
PPC2(OE): 1D1.24 (PC2), X2.1OE (OE), X2.2OE (OE)
PPC3(WR): 1D1.25 (PC3), X2.1WR (WR), X2.2WR (WR)
PPC4(BS1): 1D1.26 (PC4), X2.1BS1 (BS1), X2.2BS1 (BS1)
PPC5(XA0): 1D1.27 (PC5), X2.1XA0 (XA0), X2.2XA0 (XA0)
PPC6(XA1): 1D1.28 ((TOSC1)PC6), X2.1XA1 (XA1), X2.2XA1 (XA1)
PPC7(PAGEL): 1D1.29 ((TOSC2)PC7), X2.1PAGEL (PAGEL), X2.2PAGEL (PAGEL)
RESET8535: 1C8.2, 1R1.1, JP2.1, JR.2, RES.3, RJ1.1, S1.1 (S), S1.2 (S1), U$1.P$2
RESET(P): ISP6.5, JP2.2, RES.2
RX_AVR: 1D1.15 ((TXD)PD1), J1.2
RX_USB: 2D1.RXD, J1.1
SCK8535: 1D1.8 ((SCK)PB7), ISP6.3, JS.2, X2.1D7 (D7), X2.2D7 (D7)
SWCLK(XTAL1): 4VT3.2 (S), JX.2, X2.1XTAL1 (XTAL1), X2.2XTAL1 (XTAL1)
TRST(RESET): 1R19.1, 1VT3.3 (C), JP2.3, RES.1, RJ7.1
TX_AVR: 1D1.14 ((RXD)PD0), J2.2
TX_USB: 2D1.TXD, J2.1, JR.1
VTG: 4R5.1, 4VT2.3 (D), JV.2, RJ4.2, X2.1VCC1 (VCC), X2.2VCC1 (VCC)

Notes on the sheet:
Target Reset
Programmer Reset
orig 3R1 4e7
J HW не нужен
1R6 для J HW
HW(reset=+12v)
READY
n-ch
p-ch

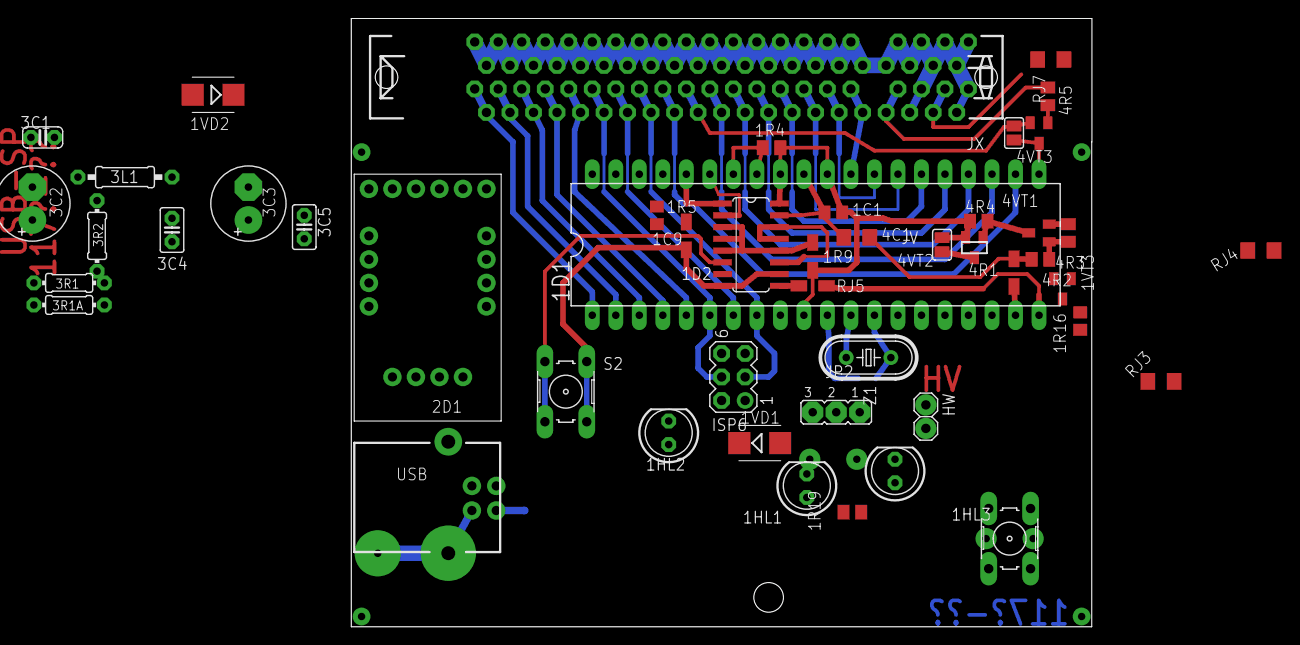
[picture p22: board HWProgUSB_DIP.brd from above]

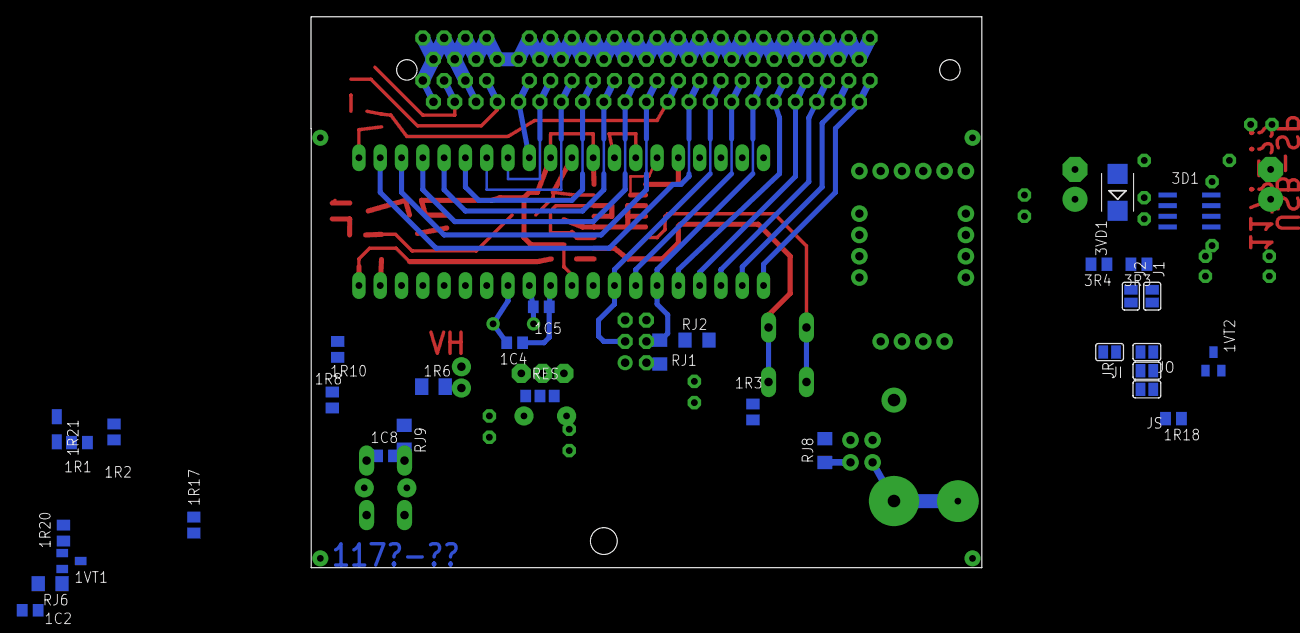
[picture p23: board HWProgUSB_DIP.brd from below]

Board: 2 copper layers, 80.0 x 65.7 mm, 82 parts (32 on the bottom side), 75 nets.

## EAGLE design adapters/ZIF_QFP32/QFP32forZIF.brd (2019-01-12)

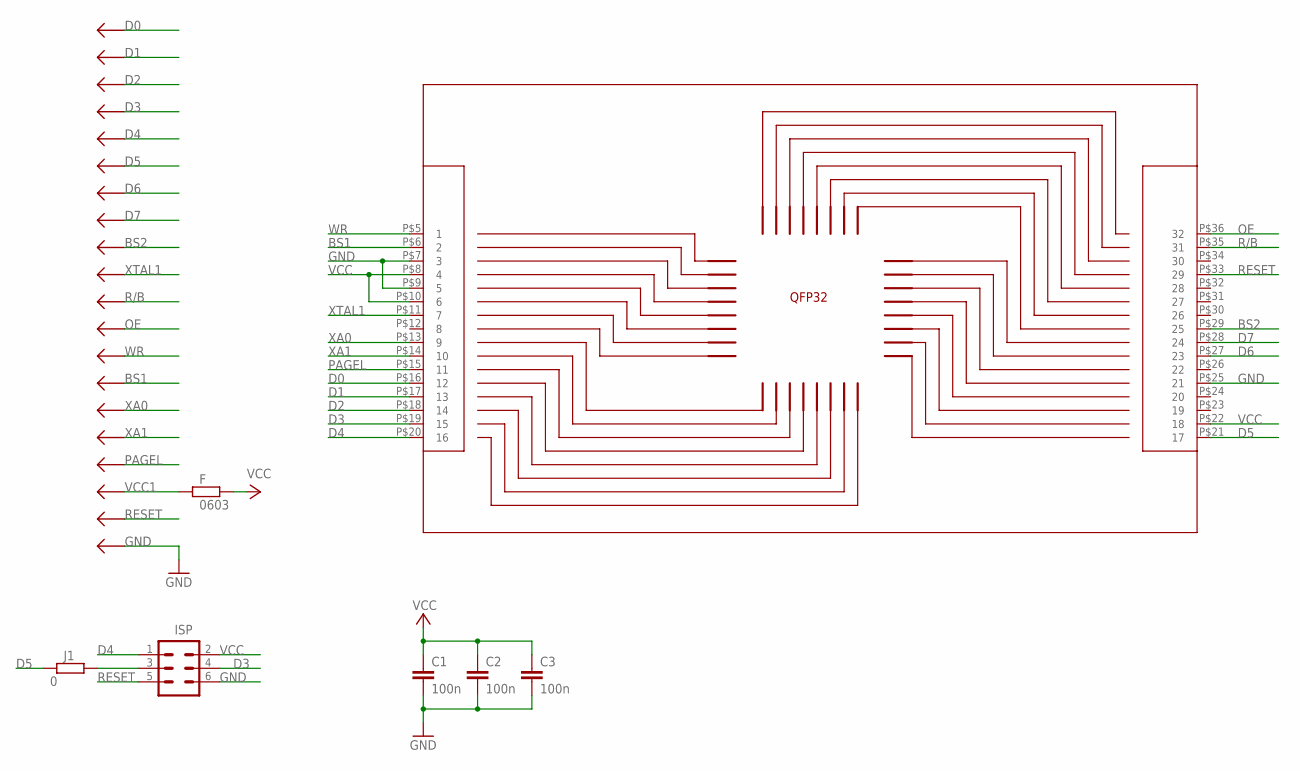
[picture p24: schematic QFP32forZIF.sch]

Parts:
C1, C2, C3: 100n; RCL_C0805
F: 0603; RCL_M0805
ISP: MA03-2
J1: 0; R1206W
U$1: PROGRAMMER_P_AVR
U$14: SA636-40; ADAPTERQFP48FORZIF

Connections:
BS1: U$1.BS1, U$14.P$6 (2)
BS2: U$1.BS2, U$14.P$29 (25)
D0: U$1.D0, U$14.P$16 (12)
D1: U$1.D1, U$14.P$17 (13)
D2: U$1.D2, U$14.P$18 (14)
D3: ISP.4, U$1.D3, U$14.P$19 (15)
D4: ISP.1, U$1.D4, U$14.P$20 (16)
D5: J1.1, U$1.D5, U$14.P$21 (17)
D6: U$1.D6, U$14.P$27 (23)
D7: U$1.D7, U$14.P$28 (24)
GND: C1.2, C2.2, C3.2, ISP.6, U$1.GND, U$1.GND01 (GND), U$1.GND2 (GND), U$1.GND03 (GND), U$1.GND04 (GND), U$1.GND05 (GND), U$1.GND06 (GND), U$1.GND07 (GND), U$1.GND08 (GND), U$1.GND09 (GND), U$1.GND10 (GND), U$1.GND11 (GND), U$1.GND12 (GND), U$1.GND13 (GND), U$1.GND14 (GND), U$1.GND15 (GND), U$1.GND16 (GND), U$1.GND17 (GND), U$1.GND18 (GND), U$1.GND19 (GND), U$1.GND20 (GND), U$1.GND21 (GND), U$1.GND22 (GND), U$14.P$7 (3), U$14.P$9 (5), U$14.P$25 (21)
unnamed: ISP.3, J1.2
OE: U$1.OE, U$14.P$36 (32)
PAGEL: U$1.PAGEL, U$14.P$15 (11)
R/B: U$1.RB, U$14.P$35 (31)
RESET: ISP.5, U$1.RESET, U$14.P$33 (29)
VCC: C1.1, C2.1, C3.1, F.2, ISP.2, U$14.P$8 (4), U$14.P$10 (6), U$14.P$22 (18)
VCC1: F.1, U$1.VCC
WR: U$1.WR, U$14.P$5 (1)
XA0: U$1.XA0, U$14.P$13 (9)
XA1: U$1.XA1, U$14.P$14 (10)
XTAL1: U$1.XTAL1, U$14.P$11 (7)

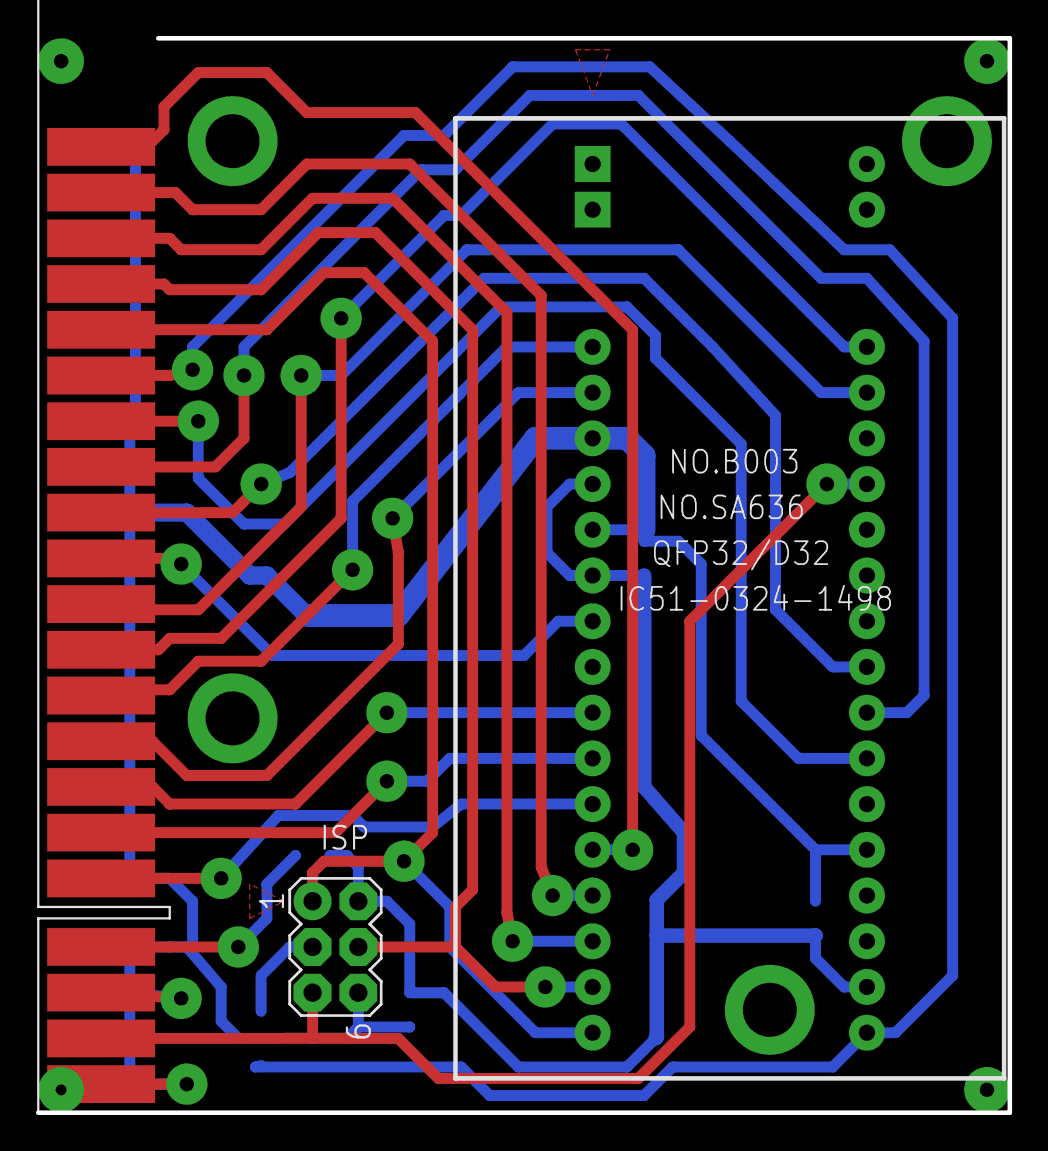
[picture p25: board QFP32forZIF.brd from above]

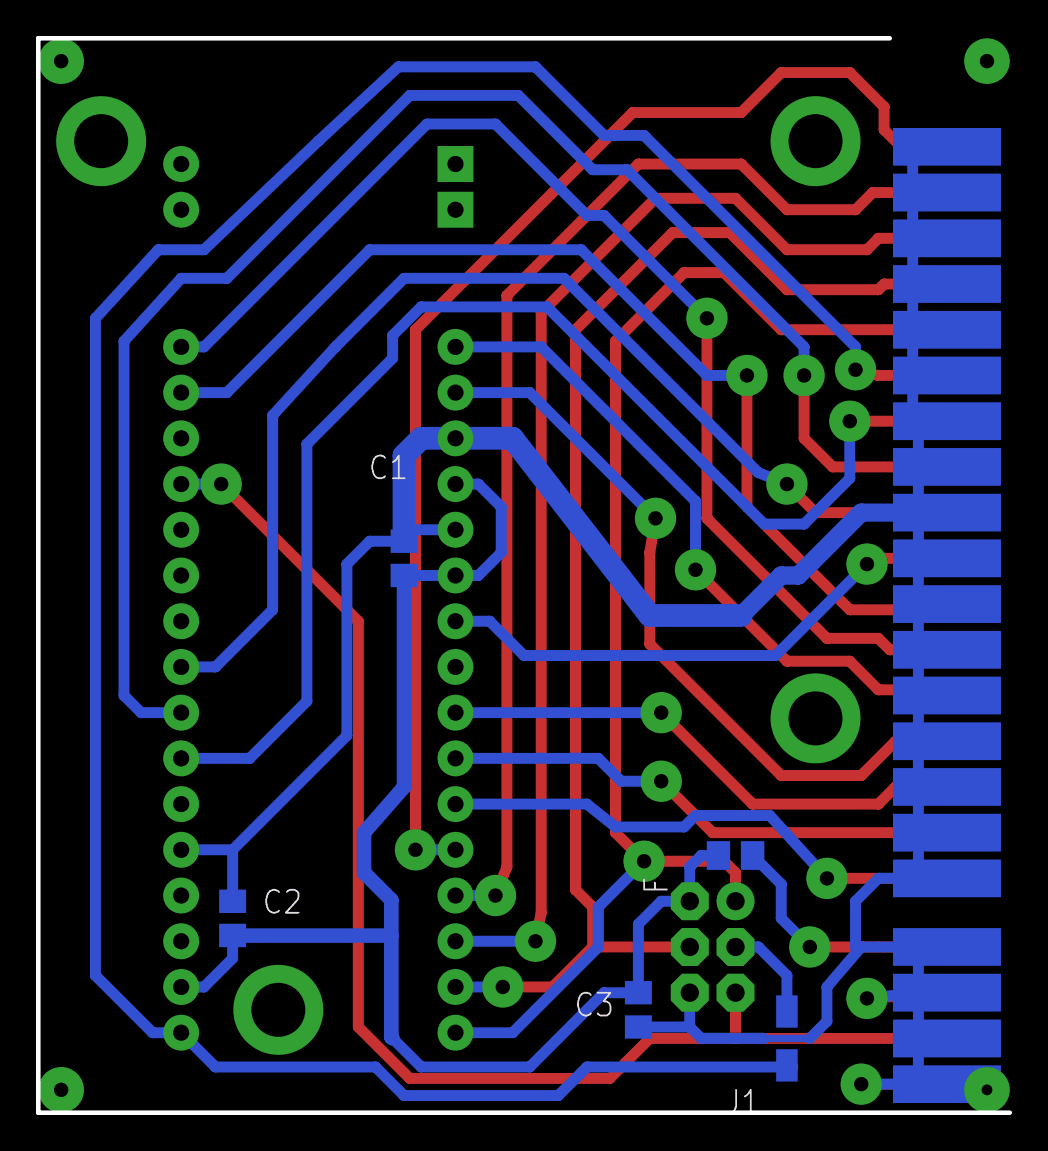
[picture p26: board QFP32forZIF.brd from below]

Board: 2 copper layers, 54.0 x 59.7 mm, 8 parts (5 on the bottom side), 22 nets.

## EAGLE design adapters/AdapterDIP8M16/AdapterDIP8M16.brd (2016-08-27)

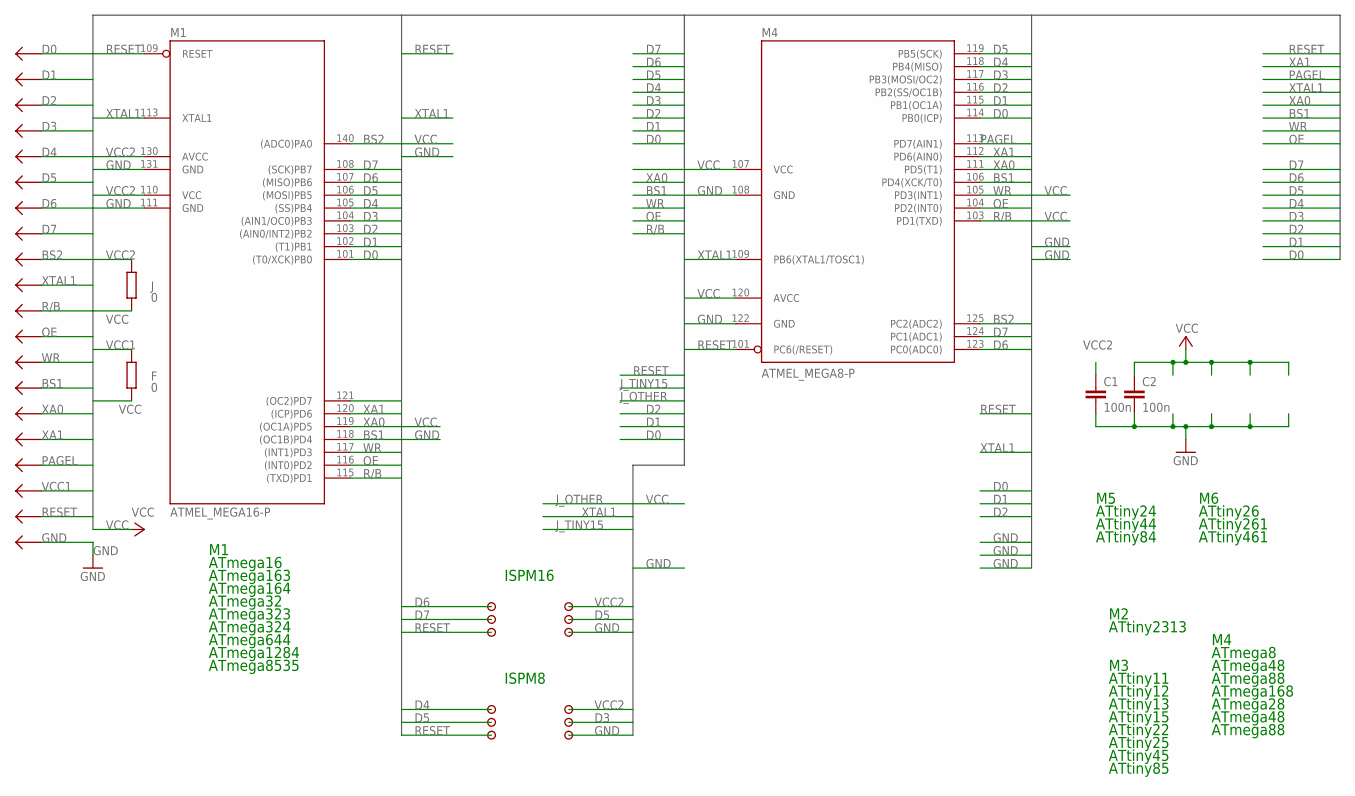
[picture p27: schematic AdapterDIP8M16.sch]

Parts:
C1, C2: 100n; RCL_C0805
F: 0; RCL_M0805
J: 0; RCL_M1206
M1: ATMEL_MEGA16-P; ATMEL_DIL40
M4: ATMEL_MEGA8-P; ATMEL_DIL28-3
U$1: PROGRAMMER_P_AVR
U$2, U$3, U$4, U$5, U$6, U$7, U$8, U$9, U$10, U$11, U$12, U$13: PIN

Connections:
BS1: M1.118 ((OC1B)PD4), M4.106 (PD4(XCK/T0)), U$1.BS1
BS2: M1.140 ((ADC0)PA0), M4.125 (PC2(ADC2)), U$1.BS2
D0: M1.101 ((T0/XCK)PB0), M4.114 (PB0(ICP)), U$1.D0
D1: M1.102 ((T1)PB1), M4.115 (PB1(OC1A)), U$1.D1
D2: M1.103 ((AIN0/INT2)PB2), M4.116 (PB2(SS/OC1B)), U$1.D2
D3: M1.104 ((AIN1/OC0)PB3), M4.117 (PB3(MOSI/OC2)), U$1.D3, U$12.P$1
D4: M1.105 ((SS)PB4), M4.118 (PB4(MISO)), U$1.D4, U$8.P$1
D5: M1.106 ((MOSI)PB5), M4.119 (PB5(SCK)), U$1.D5, U$3.P$1, U$9.P$1
D6: M1.107 ((MISO)PB6), M4.123 (PC0(ADC0)), U$1.D6, U$5.P$1
D7: M1.108 ((SCK)PB7), M4.124 (PC1(ADC1)), U$1.D7, U$6.P$1
GND: C1.2, C2.2, M1.111 (GND), M1.131 (GND), M4.108 (GND), M4.122 (GND), U$1.GND, U$1.GND01 (GND), U$1.GND2 (GND), U$1.GND03 (GND), U$1.GND04 (GND), U$1.GND05 (GND), U$1.GND06 (GND), U$1.GND07 (GND), U$1.GND08 (GND), U$1.GND09 (GND), U$1.GND10 (GND), U$1.GND11 (GND), U$1.GND12 (GND), U$1.GND13 (GND), U$1.GND14 (GND), U$1.GND15 (GND), U$1.GND16 (GND), U$1.GND17 (GND), U$1.GND18 (GND), U$1.GND19 (GND), U$1.GND20 (GND), U$1.GND21 (GND), U$1.GND22 (GND), U$4.P$1, U$11.P$1
OE: M1.116 ((INT0)PD2), M4.104 (PD2(INT0)), U$1.OE
PAGEL: M1.121 ((OC2)PD7), M4.113 (PD7(AIN1)), U$1.PAGEL
R/B: M1.115 ((TXD)PD1), M4.103 (PD1(TXD)), U$1.RB
RESET: M1.109 (RESET), M4.101 (PC6(/RESET)), U$1.RESET, U$7.P$1, U$10.P$1
VCC: C2.1, F.2, J.2, M4.107 (VCC), M4.120 (AVCC)
VCC1: F.1, U$1.VCC
VCC2: C1.1, J.1, M1.110 (VCC), M1.130 (AVCC), U$2.P$1, U$13.P$1
WR: M1.117 ((INT1)PD3), M4.105 (PD3(INT1)), U$1.WR
XA0: M1.119 ((OC1A)PD5), M4.111 (PD5(T1)), U$1.XA0
XA1: M1.120 ((ICP)PD6), M4.112 (PD6(AIN0)), U$1.XA1
XTAL1: M1.113 (XTAL1), M4.109 (PB6(XTAL1/TOSC1)), U$1.XTAL1

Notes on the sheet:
ATmega16
ATmega163
ATmega164
ATmega32
ATmega323
ATmega324
ATmega644
ATmega1284
ATmega8535
ATtiny2313
ATtiny11
ATtiny12
ATtiny13
ATtiny15
ATtiny22
ATtiny25
ATtiny45
ATtiny85
ATmega8
ATmega48
ATmega88
ATmega168
ATmega28
ATtiny24
ATtiny44
ATtiny84
ATtiny26
ATtiny261
ATtiny461
ISPM16
ISPM8

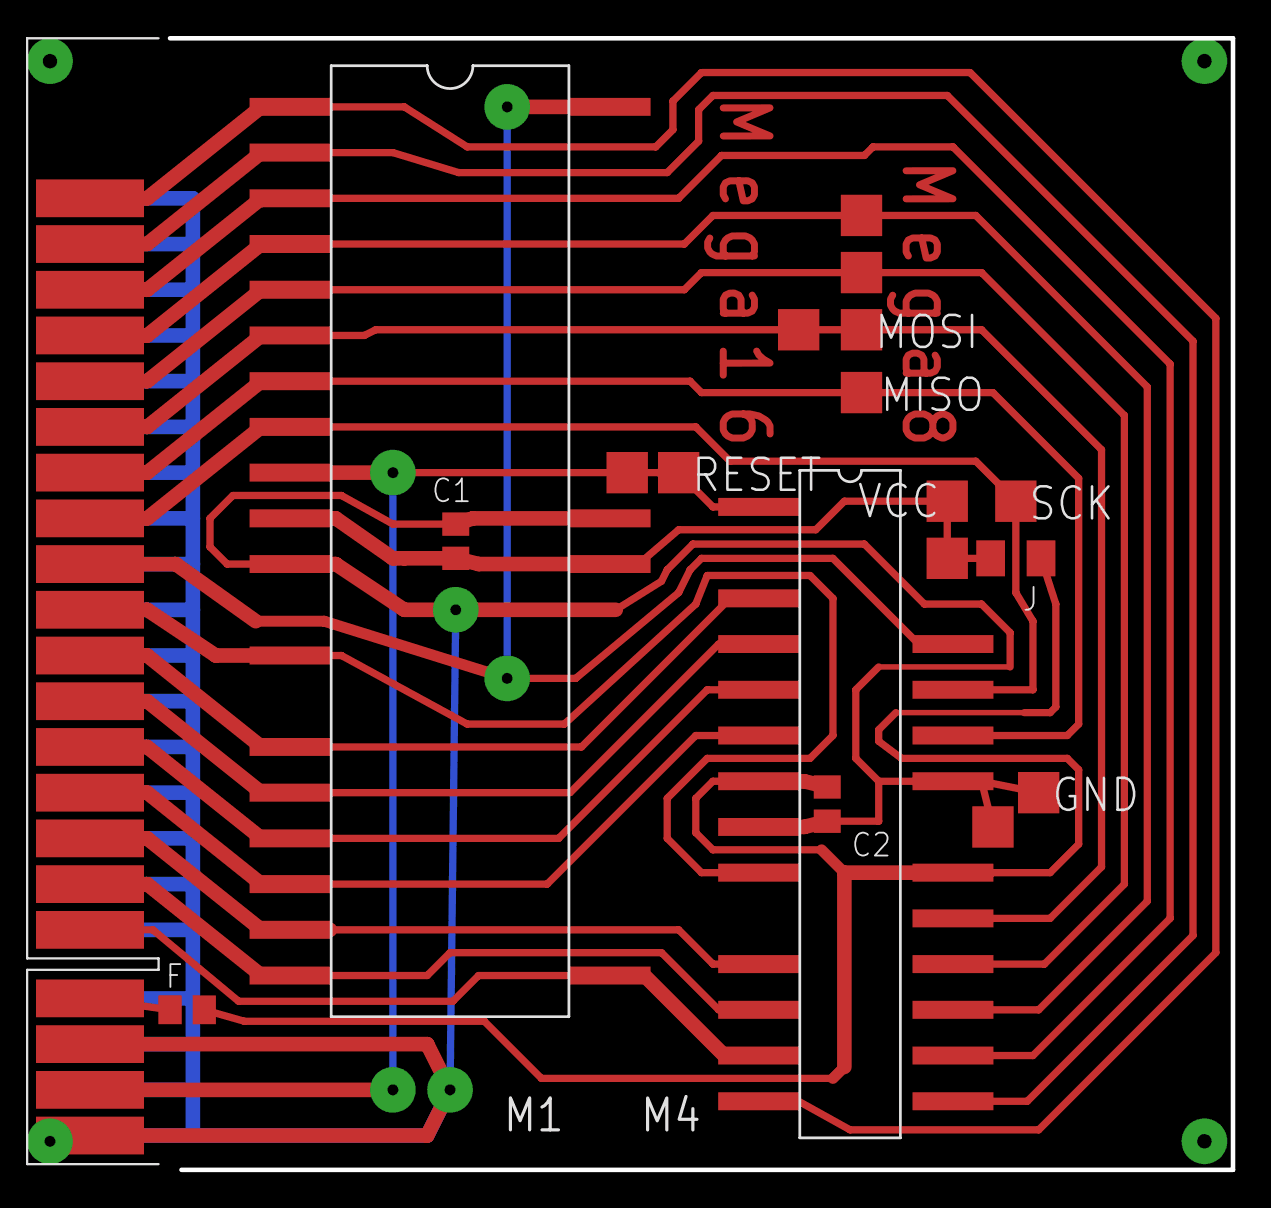
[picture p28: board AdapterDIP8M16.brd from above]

Board: 2 copper layers, 59.1 x 62.9 mm, 19 parts (0 on the bottom side), 22 nets.

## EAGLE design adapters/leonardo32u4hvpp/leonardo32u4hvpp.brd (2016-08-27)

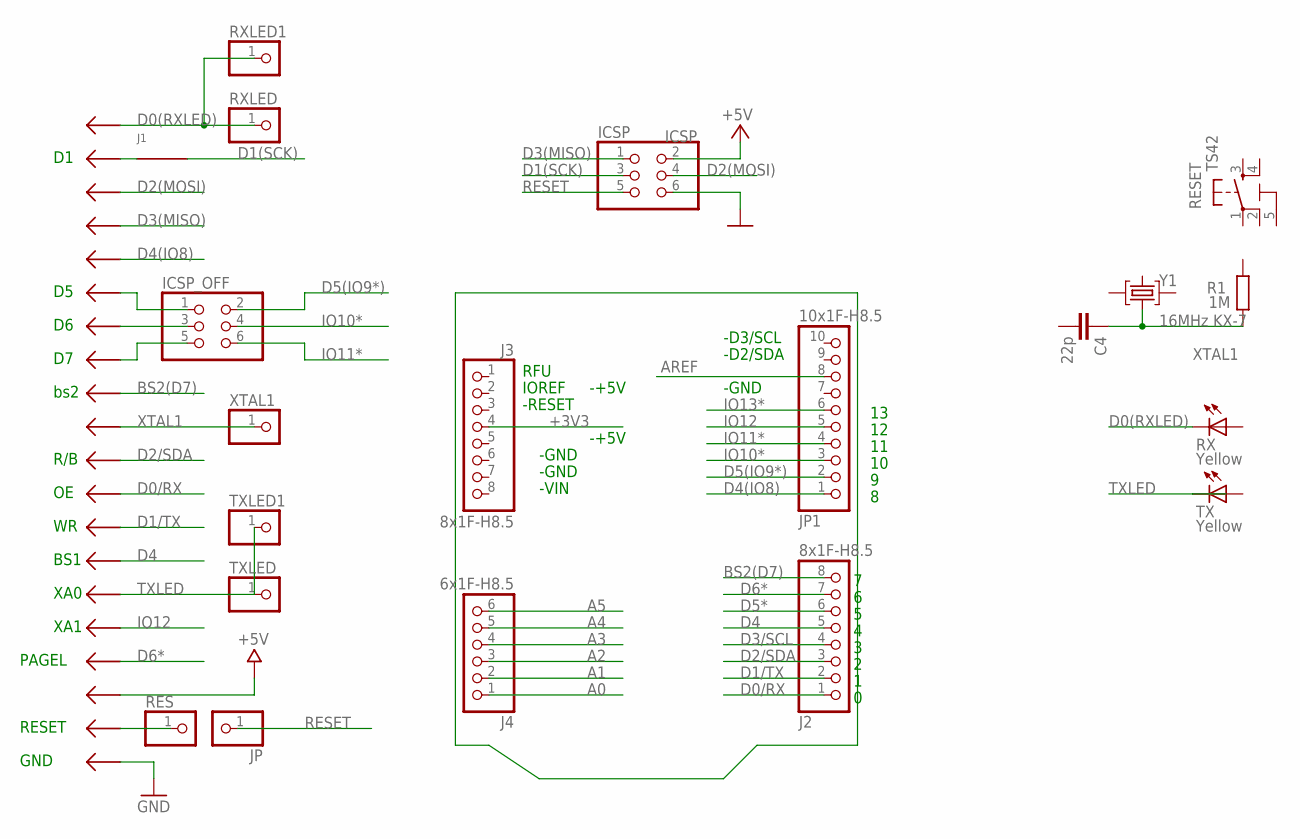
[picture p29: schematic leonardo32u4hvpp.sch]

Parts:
C4: 22p; C0603-ROUND
ICSP: ICSP; 2X03
ICSP_OFF: PINHD-2X3; 2X03
J1: J; R1206W
J2, J3: 8x1F-H8.5; 1X08
J4: 6x1F-H8.5; 1X06
JP: PINHD-1X1; 1X01
JP1: 10x1F-H8.5; 1X10
R1: 1M; R0603-ROUND
RES: PINHD-1X1; 1X01
RESET: TS42
RX: Yellow; CHIPLED_0805
RXLED, RXLED1: PINHD-1X1; 1X01
TX: Yellow; CHIPLED_0805
TXLED, TXLED1: PINHD-1X1; 1X01
U$2: PROGRAMMER_P_AVR
XTAL1: PINHD-1X1; 1X01
Y1: 16MHz KX-7; CRYSTAL-3.2-2.5

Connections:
5-GND: RESET.5 (5-GND)
+3V3: J3.4
+5V: ICSP.2, U$2.VCC
A0: J4.1
A1: J4.2
A2: J4.3
A3: J4.4
A4: J4.5
A5: J4.6
AREF: JP1.8
BS2(D7): J2.8, U$2.BS2
D0(RXLED): RX.C, RXLED.1, RXLED1.1, U$2.D0
D0/RX: J2.1, U$2.OE
D1(SCK): ICSP.3, J1.1
D1/TX: J2.2, U$2.WR
D2(MOSI): ICSP.4, U$2.D2
D2/SDA: J2.3, U$2.RB
D3(MISO): ICSP.1, U$2.D3
D3/SCL: J2.4
D4: J2.5, U$2.BS1
D4(IO8): JP1.1, U$2.D4
D5(IO9*): ICSP_OFF.2, JP1.2
D5*: J2.6
D6*: J2.7, U$2.PAGEL
GND: ICSP.6, U$2.GND, U$2.GND01 (GND), U$2.GND2 (GND), U$2.GND03 (GND), U$2.GND04 (GND), U$2.GND05 (GND), U$2.GND06 (GND), U$2.GND07 (GND), U$2.GND08 (GND), U$2.GND09 (GND), U$2.GND10 (GND), U$2.GND11 (GND), U$2.GND12 (GND), U$2.GND13 (GND), U$2.GND14 (GND), U$2.GND15 (GND), U$2.GND16 (GND), U$2.GND17 (GND), U$2.GND18 (GND), U$2.GND19 (GND), U$2.GND20 (GND), U$2.GND21 (GND), U$2.GND22 (GND)
IO10*: ICSP_OFF.4, JP1.3
IO11*: ICSP_OFF.6, JP1.4
IO12: JP1.5, U$2.XA1
IO13*: JP1.6
unnamed: J1.2, U$2.D1
unnamed: ICSP_OFF.5, U$2.D7
unnamed: ICSP_OFF.3, U$2.D6
unnamed: ICSP_OFF.1, U$2.D5
unnamed: RES.1, U$2.RESET
RESET: ICSP.5, JP.1
TXLED: TX.C, TXLED.1, TXLED1.1, U$2.XA0
XTAL1: C4.1, R1.1, U$2.XTAL1, XTAL1.1, Y1.1 (C1)

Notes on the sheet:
IOREF
RFU
bs2
R/B
BS1
XA0
XA1
PAGEL
RESET
GND
-D2/SDA
-D3/SCL
-GND
-VIN
-RESET
-+5V


Board: 2 copper layers, 68.6 x 53.3 mm, 21 parts (1 on the bottom side), 25 nets.

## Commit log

2018-10-19 add 3v3 led ..
    [HWProgUSB.brd, HWProgUSB.sch]
2018-11-23 add doc panel
    [HWProgUSB.brd]
2018-11-27 qfp48 adapter
    [AdapterQFP48forZIF.brd, AdapterQFP48forZIF.sch]
2018-11-30 rename adapter
    [QFP48forZIF.brd, QFP48forZIF.sch, mega8pin.sch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]

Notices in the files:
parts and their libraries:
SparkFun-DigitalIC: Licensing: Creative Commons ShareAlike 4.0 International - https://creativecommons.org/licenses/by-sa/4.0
